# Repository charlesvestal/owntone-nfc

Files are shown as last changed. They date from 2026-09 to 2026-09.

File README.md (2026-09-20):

# owntone-nfc

An NFC "vinyl jukebox" for the Raspberry Pi. Put a card on the reader and an
album plays; take it off and it stops.

Audio goes to a local speaker, to AirPlay 2 speakers such as HomePods, or both.
When a card is removed and the grace period expires, the AirPlay session is
released so the speakers are free for anything else in the house — and your
speaker choice is remembered for the next card.

## The idea

Simulate a record player. Put the record on, it plays from the start. Take it
off, it stops. The card is a physical object that does exactly one thing, and
nothing about the interaction is hidden in an app.

That constraint drives the design: no resume position, no skip button on the
box, no state the card secretly carries. Anything player-shaped — transport,
volume, speaker selection, browsing — belongs to OwnTone's own web UI, which
already does it well. This project builds only what OwnTone cannot: turning a
card on a reader into playback.

## How it works

**OwnTone** owns the music library, playback, and the audio outputs. It is the
only mature AirPlay 2 *sender* on Linux, and since v29.0.139 it defaults to
AirPlay 2 with PTP timing, which is what keeps a HomePod stereo pair in sync.

A small Python service reads card presence from a **PN532 NFC HAT** over UART
and drives OwnTone through its JSON REST API.

| Module | Responsibility |
|---|---|
| `reader.py` | Card presence. Emits `card_present(uid)` / `card_removed()`, nothing else. |
| `owntone.py` | Thin REST client. Knows nothing about cards. |
| `cards.py` | UID → album mapping, persisted as YAML. |
| `outputs.py` | Speaker-selection snapshot, so the choice survives a release cycle and a reboot. |
| `controller.py` | The state machine. The only file with interesting logic, and where the tests live. |
| `web.py` | Card registration, and the admin page. Deliberately tiny. |
| `cardart/` | Finds cover art for albums still awaiting a card and lays it out as print-ready A4 sheets. Off the playback path entirely. |

Card mappings store **library-root-relative paths**, never absolute paths and
never OwnTone's numeric IDs — so a rebuild onto a new SD card doesn't cost you
a single re-registration.

Every album is meant to have exactly one card. Nothing in the format enforces
it, so the admin page flags any album holding more than one — with a hundred-odd
cards registered, a duplicate is otherwise invisible until two of them turn out
to play the same record.

## Hardware

| Part | Notes |
|---|---|
| **Raspberry Pi 4** | A 3B+ would likely do. Built and tested on a Pi 4. |
| **Waveshare PN532 NFC HAT** | Sits on the GPIO header. Any PN532 board with a UART mode works. |
| **NFC cards or tags** | See the note on card types below. |
| SD card | 16GB is plenty if the music lives on a NAS. |
| Speakers | Anything OwnTone can drive: the Pi's 3.5mm jack, a USB/I2S DAC, or AirPlay 2 speakers such as HomePods. |

### Configuring the HAT

**Set it to UART**, not I2C or SPI. This matters: `nfcpy` is the library with a
real card-*presence* API rather than read-a-UID-once, and it does not support
I2C at all. Continuous presence detection is the entire product - the card has
to keep saying "I am still here".

**DIP switches** — 1–6 OFF, 7 and 8 ON:

| # | 1 | 2 | 3 | 4 | 5 | 6 | 7 | 8 |
|---|---|---|---|---|---|---|---|---|
| Signal | SCK | MISO | MOSI | NSS | SCL | SDA | **RX** | **TX** |
| Set to | OFF | OFF | OFF | OFF | OFF | OFF | **ON** | **ON** |

**Jumpers** — the two labelled `I0`/`I1` (or `L0`/`L1`) set the chip's protocol,
separately from the DIP switches. For UART both go to **L**. Get the switches
right and the jumpers wrong and the reader sits there silent.

**Leave `RSTPDN` jumpered to `D20`.** The service pulses that line to reset the
PN532 when it stops responding, which a restart can cause. Without the jumper a
wedged reader needs a power cycle.

`provision.sh` handles the Pi side: freeing the serial console and putting the
real PL011 UART on GPIO14/15 (the mini-UART's baud rate drifts with the VPU
clock and gives a reader that works only intermittently).

### Card types

**For new cards, buy NTAG213 or NTAG215.** Different tags report presence very
differently: motionless on the same reader, an NTAG213 held continuously for 11
seconds, while a 4-byte card was reported absent and re-found about 29 times a
second. That flicker is how the PN532 answers a re-select for that technology,
not the card moving — and the debounce absorbs it completely, with 19x margin
measured. Both kinds work; NTAG simply starts with more room.

The UID tells you which you have — 7 bytes starting `04` is an NTAG, 4 bytes is
Mifare-Classic-style. Insist on the chip name in the listing; "13.56MHz NFC
sticker" with no chip named is usually the wrong one. 213, 215 and 216 differ
only in memory, which does not matter here: the card carries no data, only its
UID.

Presence is debounced in software to cope, tuned by `presence_debounce_s`. If
cards stutter or fail to play, measure yours with `spikes/presence_check.py`
and raise that value. Measure with your least reliable card, not the first one
to hand.

### If it goes in an enclosure

Test networking in its final position before assembling everything, and **put
it on 2.4 GHz**. This board's 5 GHz receive path does not work: it associates,
completes the handshake, reports itself connected — and receives nothing. Not
"less", nothing. Transmit negotiates 390 Mbit/s while receive sits pinned at
6 Mbit/s, the floor, and zero bytes arrive. DHCP timing out is the first
symptom you notice, not the fault.

This was blamed on signal margin for a long time, and that was wrong: it fails
at -63 dBm just as completely as at -69, while a Mac in the same room uses the
same 5 GHz AP at -73 dBm without trouble. Don't go hunting for a few dB.

The failure is binary rather than gradual, and it does not announce itself.
[`docs/runbook.md`](docs/runbook.md) has the measurements and the four
plausible explanations that turned out to be wrong.

## Getting started

Burn Raspberry Pi OS Lite 64-bit, then:

```bash
git clone <this repo> /home/pi/owntone-nfc
sudo bash /home/pi/owntone-nfc/deploy/provision.sh
```

Copy albums to `/srv/music/<Artist>/<Album>/` (Samba share at
`smb://jukebox.local`), then open **http://jukebox.local:8080**, tap a card,
pick an album, save.

The same page collects cover art for albums that have no card yet, so you can
print a sheet of them. A search that picks the wrong cover can be corrected by
pinning a specific image URL; those corrections are hand-made judgements and
`backup.sh` keeps them alongside the card registry.

Pick your speakers in OwnTone at **http://jukebox.local:3689**. The jukebox
remembers them.

### Registering a stack of cards

Kneeling next to the box to register a shelf of albums gets old. Plug a USB
NFC reader into your laptop instead:

```bash
python3 -m pip install pyscard
python3 tools/desk_reader.py --host jukebox.local:8080
```

Tap a card, pick the album in the Register tab, save, tap the next. Each tap
prints `known card` or `NEW card`, so you can work through a pile without
watching the browser.

The scan is **identification only** — it cannot start, stop or switch a
record, so registering at a desk never interrupts what is playing in the
room. `--dry-run` prints UIDs without telling the jukebox, and `--silence`
turns off the reader's beep for good.

Tested with an ACS ACR122U, which reports UIDs byte-identical to the PN532 on
the box. Worth confirming that for any other reader before registering a
stack: scan a card you have already registered and check it matches
`cards.yaml`. Some readers report the UID byte-reversed, which would leave
every card you register pointing at nothing.

## Documentation

- **[`docs/runbook.md`](docs/runbook.md)** — hardware settings, the Wi-Fi and
  AirPlay gotchas, a symptom table, and how to rebuild. **Read this first when
  something is broken.**
- **[`docs/superpowers/specs/`](docs/superpowers/specs/)** — the design, and
  what hardware testing proved wrong about it.

## One thing worth knowing

**`user_agent = "AirPlay/999.0.0"` is required in `owntone.conf`.** Apple OS 27
gates `GET /info` on the User-Agent and returns 403 to OwnTone's default, so
AirPlay speakers stop working as they update. `provision.sh` sets it. Upstream:
[owntone#2042](https://github.com/owntone/owntone-server/issues/2042).

Environment-specific troubleshooting — networking, enclosures, recovery — is in
[`docs/runbook.md`](docs/runbook.md).

## Development

```bash
python3 -m venv .venv && .venv/bin/pip install -e '.[dev]'
.venv/bin/pytest
```

The suite runs on macOS with no hardware: `nfcpy` is imported lazily and the
reader has a fake. Note what that means — the tests prove the state machine's
logic, not that OwnTone accepts the calls. Several bugs found on real hardware
were invisible to a green suite because the mocks encoded the same assumptions
as the code.

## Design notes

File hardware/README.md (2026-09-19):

# Stand

A slanted face that holds the card like a record on a shelf, with the Pi
mounted directly behind it and **the back left open**.

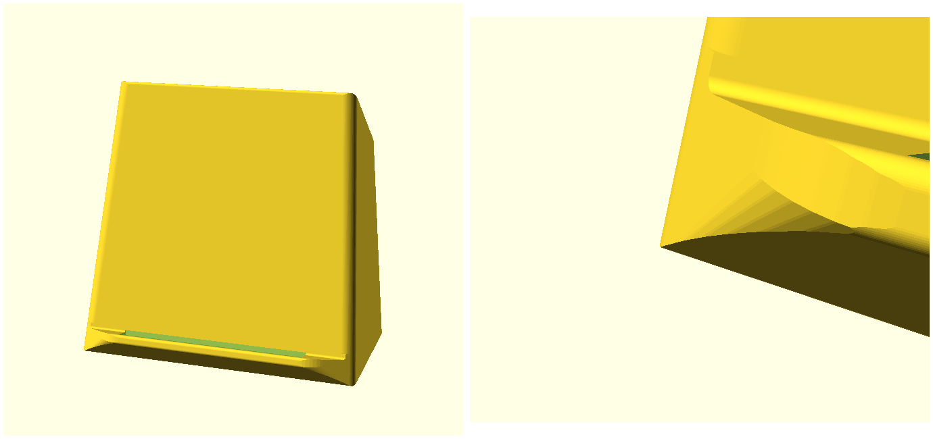
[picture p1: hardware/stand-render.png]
render


Rendered above: front, three-quarter, and the open back.

The open back is the whole idea. The Pi's ports face into it, so cables plug
straight into the board — no panel cutouts to get wrong, no internal extension
cables, and the airflow comes free. From the front you see a sleeve on a
stand; everything else is behind it.

The 15° lean means gravity holds the card against the face. The current box
has it vertical, so a strip of felt is doing all the work.

## You screw in the HAT, not the Pi

They share the 85 x 56 mm footprint and the same hole pattern, so either will
bolt to the face — but only one is right. The coil has to be the thing nearest
the card. Mount the **Pi** to the panel and the HAT ends up behind it on the
GPIO header, roughly 20 mm further from the card with the Pi's ground planes in
between; it will read badly or not at all.

So: **HAT bolted to the face, coil toward the card, Pi hanging off the back of
it** on the GPIO header.

## Measure the gap first

The HAT's tall top-side parts — the 1x17 breakout and the 2x3 jumper block —
stand **7.6 mm proud** of the board (measured from Waveshare's STEP model), and
in this orientation they face the panel. That forces ~11 mm standoffs, which
puts the coil about **14 mm** behind the card.

**That gap, not the panel thickness, is what decides whether a card reads.** At
11 mm standoffs the thinned window over the coil buys nothing at all — it only
matters if the HAT is nearly touching the panel.

So print the gauge and find out what your cards actually tolerate:

```sh
openscad -o gauge.stl -D 'part="coupon"' stand.scad
```

Six hollow pads, 6–16 mm. Sit the HAT face down on a pad, put your **worst**
card on top — a 4-byte Mifare-style one, 78 of the 132 are that type — and run
`spikes/presence_check.py`. Watch the **presence cycle count**, not simply
whether it reads: a marginal gap reads fine held still and falls apart when a
card is set down.

Then pick:

- **If 14 mm reads solidly**, keep `standoff_h = 11` and set `window_t = face_t`
  (the window is pointless at that distance).
- **If it doesn't**, the coil needs to come closer, which means a relief opening
  in the panel for those tall headers — hidden behind the card — and short
  standoffs. That gets the coil to about 7 mm. Ask and I'll add it.

## Then the stand

```sh
openscad -o stand.stl stand.scad
```

Defaults give a ~120 × 123 mm face, 66 mm deep, for a 95 mm card. Everything is
parametric — card size, lean, lip, panel thickness, Pi hole spacing, antenna
window — at the top of `stand.scad`.

**Measure the tag, not the HAT.** The HAT is already in the file: Waveshare's
own dimension drawing gives an 85 x 56 mm board — the same footprint as the Pi,
not a short 65 mm HAT — with a 37.4 x 37.8 mm coil panel centred 17.0 mm along
the long axis and 2.3 mm across from the board centre, on the far side from the
GPIO header.

So the only thing to measure is where the tag sits on your cards, and that is
done: **30 mm in from the left edge and 65 mm down from the top, measured on the
back.** Viewing from the front mirrors left to right but not top to bottom, so
in the model's frame that is `tag_dx = 17.5`, `tag_dy = -17.5` — the lower right
quadrant from the front, however it looks from behind.

With the HAT unflipped that lands the Pi almost exactly centred (0.5 mm off),
needing only a 76 mm panel against the 120 mm the card already demands. Flipped
it would want a 144 mm one, so `hat_flipped = false`.

The model then works out where the Pi has to go to put the coil on the tag, and
`hat_flipped` mirrors the offset by turning the HAT end-for-end — which is
usually what decides whether the coil can reach the tag at all. Three assertions
catch the ways this goes wrong: bosses in the side wall, bosses in the base, and
a coil window running off the edge of the card.

The panel is thinned **from behind**, so the outside stays flat and rigid
while the reader only has `window_t` of plastic to see through.

## Design notes

Every visible edge is chamfered and the vertical corners radiused, so the form
catches light along its arrises instead of showing a raw printed corner. The top
is **cut back** rather than coming to a point, and the sides **rake inward** as they rise — the taper an arcade cabinet uses, and for the same
reason: straight sides read as a box, angled ones as a made object. The rake is
bounded by the card, which is square and cannot be encroached on.

The card **stands on a lip** and leans back against the face — gravity holds it,
which is the whole reason for the slant. The felt sits in a **recess** in the
lip's top so it finishes flush instead of proud, and the lip's underside is
chamfered back to the face: a ledge projecting from a panel that already leans
back is a full overhang, and would otherwise need support exactly where the
finish shows most. There is deliberately **no hole in the front**; a scallop cut
in the panel reads as damage rather than detail.

The **side walls carry back** to `back_h` of the front height, so the Pi and the
cavity aren't on show from the side. Lower looks lighter; too low and it's a
blade on a plinth.

There was a shadow reveal round the base too, to lift the body optically. It is
gone: the lip covers it across the front, so it ran three-quarters of the way
round and stopped, which reads as a mistake rather than a detail. The lip
already gives the front its horizontal line.

`face_w` takes the **larger** of "wide enough for the card" and "wide enough for
the Pi wherever your tag offset puts it". That second case is not hypothetical —
a mounting boss that lands on the side wall merges into it, vanishes from the
render, and is only discovered when the Pi won't screw down.

## Printing notes

- **Orientation**: base down, as modelled. The face is 15° off vertical, which
  is well within overhang tolerance, and the lip is chamfered underneath so it
  needs no support.
- **No metal near the face.** Screws, heat-set inserts and magnets all kill NFC
  coupling. The standoffs take self-tapping M2.5 straight into plastic.
- **Keep the Pi's USB-C/HDMI corner clear** of anything dense — that's the Wi-Fi
  antenna, and it has little margin to spare.
- **Felt**: `felt_w` / `felt_t` cut a recess in the lip so the strip finishes
  flush instead of sitting proud.

## Rendering on Apple Silicon

The Homebrew and 2021.01 OpenSCAD builds are Intel-only. Either install
Rosetta (`softwareupdate --install-rosetta`) or fetch an arm64 development
snapshot from openscad.org.

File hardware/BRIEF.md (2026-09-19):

# Brief: card stand for the NFC record player

## What the object is

A printed 95 × 95 mm album-art card stands on it, leaning back, displayed like
a sleeve on a shelf. A PN532 NFC HAT behind the card reads a tag in the card; a
Raspberry Pi 4 hangs off the HAT on its GPIO header. Put the card on, the album
plays; take it off, it stops. It lives in a living room next to speakers. **The
card is the interface and the hero — the object should be quiet.**

Design language: Dieter Rams. Continuous lines, nothing applied, nothing fussy.

## Hard constraints — all measured, none negotiable

| | |
|---|---|
| Card | 95 × 95 mm, ~0.5 mm thick, leans against the face |
| Tag in the card | centre **+17.5 mm right, −17.5 mm down** from the card's centre, **viewed from the front** |
| PN532 HAT | 85 × 56 mm board |
| HAT coil panel | 37.4 × 37.8 mm, centred **+17.0 mm along the long axis, +2.3 mm across** from the board's centre, on the opposite side from the GPIO connector |
| HAT tall parts | 1×17 header and 2×3 jumper block stand **7.6 mm proud** of the board and face the panel |
| Coil to card | ~14 mm. **Confirmed to read reliably — do not trade complexity to reduce it.** |
| Raspberry Pi 4 | 85 × 56 mm, hangs behind the HAT on the GPIO header; ~30 mm of stack |
| Pi ports | **face upward.** Forced, not chosen — see below |

**The HAT is the board nearest the card**, with the Pi behind it. Mounting the
Pi to the face instead puts the HAT ~20 mm further away with the Pi's ground
planes in between; it will not read.

**The coil must land on the tag.** That admits exactly one HAT orientation
(long axis horizontal, GPIO edge down), which is what forces the Pi's port edge
to face **up**. Everything else follows from this.

**Cables: the owner will not buy any.** Straight USB-C and 3.5 mm leads only.
A straight plug stands ~20–25 mm above the port plus bend radius, so either the
body is ~120 mm tall or **the back is genuinely open** and cables leave
rearward. The back should be open.

**No fasteners.** The owner has no M2.5 hardware and does not want to buy any.
Current solution, which works: the board's bottom edge drops into two seats and
leans **backward** onto two ribs — gravity holds it, as it does the card.

**Enclosed from normal view.** Solid face, solid sides. Nothing on the front
face but the card — no screws, no caps, no features.

## Printing

- FDM, Bambu, printed **base-down in one piece, no supports**.
- Nothing may overhang more than ~45° from vertical.
- Watertight: one connected component, zero non-manifold edges, flat bottom at z=0.

## The unresolved problem

**Where the lip meets the face, at the corners.** Everything else is settled.

The owner's words, in order, over six failed attempts:

> "the lip's edges and the body's don't meet well. there's a curve into a hard edge, instead of anything continuous"
> "think continuous smooth lines", "dieter rams curves"
> "where the lip connects also needs to curve out to meet the face / edge of the body"
> "when viewed from above the contour of the body and the lip should look like this" — a sketch of a long straight front with an **S at each end** sweeping back into the body's sides
> "do you see how it reaches the OUTER flat edge as opposed to the FRONT flat face"
> "either make the lip the width of the uncurved part of the face or make that part of the face transition to the outer curve of the lip. the sharp transition has to go"

**Do not guess at this from the description — it has been guessed at six times
and got worse.** A plan view with a millimetre scale is at
`~/Desktop/jukebox-stand/plan-with-scale.png`; get the owner to mark the two
numbers, and build to them.

### What has already been tried, and why each failed

| Attempt | Why it failed |
|---|---|
| Lip as a separate solid, clipped to its own plan | Its corner arcs sat at a different depth from the body's; across the body's corner radius the lip stayed at full projection while the face was already turning away, so they met at an angle |
| Lip inset by `corner_r`, returning on a 15 mm arc | Crossed the face at ~66°, leaving a cusp; the return radius is not the problem |
| Larger return radii (26, 32 mm) | Shallower crossing but the shelf under the card's outer corners disappears |
| Cove (morphological closing) at the junction | Rounds concave plan corners, but the visible cusp is where the lip's chamfered *underside* converges — a 3D feature a 2D closing cannot touch |
| Explicit tangent S drawn as a polygon | Correct in 2D, but destroyed by `hull()` — see traps |
| Lip narrowed to the face's flat width | Latest state. Still reads as reaching the body's outer edge |

## Traps — every one of these cost a cycle

- **`hull()` takes the CONVEX hull.** It silently deletes concave plan geometry. An explicit S-curve was erased by it twice before this was spotted. Loft with successive hulls only where the outline is convex.
- **Exact coincidence or tangency between solids produces non-manifold edges** in CGAL. A lip meeting a panel at exactly zero volume became a separate shell; cone bases sitting exactly on a wall produced bad edges; a lip ending exactly on a tangent point produced four. Always overlap by a few tenths.
- **`offset(r = -n)` on a 2D profile shrinks it in BOTH axes.** Using it to compensate for a Minkowski sum ate 5 mm of the lip's height and deleted it.
- **Features built in the face's tilted frame do not respect the base plane.** The lip and the boss cones both hung below z=0. Trim the whole part to z ≥ 0.
- **A cutter that runs past its target keeps cutting.** With the coil window's thinning disabled, its cutter still carved 4 mm behind the panel and put gaps in the standoff cones.
- **The panel leans back, so gravity pulls the board AWAY from it.** An earlier design had the board resting on the panel; it would have fallen off. It must lean backward onto ribs.
- **Printed bosses off the face are infeasible.** The coil reaches within ~3.3 mm of the HAT's mounting holes, and a boss 11 mm off a near-vertical face needs ~15 mm of 45° gusset, which lands on the coil. A snap cantilevered off the panel is the same mistake.
- **Two modules with the same name:** OpenSCAD silently uses the last one. A stale `body()` was rendered for several rounds.

## Verification — not optional

OpenSCAD (native, universal binary; the Homebrew one is Intel-only and Rosetta
is not installed):

    /Users/charlesvestal/.claude/jobs/323f8796/tmp/oscadmnt/OpenSCAD.app/Contents/MacOS/OpenSCAD

**Render front, three-quarter, back, side and a TOP/PLAN view, and LOOK at
every one with the Read tool.** Several faults here were invisible in a
three-quarter view and obvious in plan. Do not declare anything done without
looking. Save renders where the owner can open them — they cannot see images
that are only read.

**Then run the owner's own slicer**, which is the authority:

    /Applications/BambuStudio.app/Contents/MacOS/BambuStudio --info file.stl

It reports `manifold` and `number_of_parts`. It caught a floating snap hook
that both a render and a hand-rolled mesh check had missed. Nothing goes to the
owner without `manifold = yes` and `number_of_parts = 1`.

## Where things are

- `hardware/stand.scad` — current design, v1 shape: tapered wedge, raked sides, open back, integral lip, seats and ribs, no fasteners. **This is the shape the owner wants.**
- `hardware/stand2.scad` — an alternative that was rejected (open at the top).
- `~/Desktop/jukebox-stand/` — STLs and renders the owner looks at.

## Deliver

A corrected `hardware/stand.scad`, renders in `~/Desktop/jukebox-stand/`, an
STL that passes both the mesh check and the slicer check, and a plain statement
of what was changed and anything still unresolved. Do not commit to git.

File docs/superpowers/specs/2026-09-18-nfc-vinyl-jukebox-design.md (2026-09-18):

# NFC Vinyl Jukebox — Design

**Date:** 2026-09-18
**Status:** Approved, pending Spike 0

## Goal

Rebuild a contactless RFID/NFC music player on a Raspberry Pi. Placing an NFC card
on the reader plays an album; removing it stops playback. Audio must be able to go
to a local speaker *or* to AirPlay 2 HomePods, and the HomePods must be released
when playback ends so they are free for other senders.

**North star: simulate vinyl.** Put the record on, it plays from the start. Take it
off, it stops. The physical object is honest — no skip button, no resume, no state
hidden in the card.

## Why not Phoniebox

The previous build used Phoniebox. It remains the dominant project and v3 (Python
rewrite) is near-default, but it is the wrong fit here for one reason: **MPD, its
playback engine, has no AirPlay output at all.**

The only documented Phoniebox+HomePod recipe requires Phoniebox v2 + MPD on a
non-default port + OwnTone + PulseAudio + `snd-aloop` + patched shell scripts. Its
author describes it as "very convoluted" and reports that **v3's PulseAudio layer
would not pair with HomePods**. Adopting it means carrying local patches against a
moving upstream, and local-vs-AirPlay switching stays awkward because MPD has no
concept of AirPlay.

OwnTone (formerly forked-daapd) is the only mature AirPlay 2 *sender* on Linux.
Since v29.0.139 its default AirPlay mode is AirPlay 2 with PTP timing. It treats
local ALSA and AirPlay devices as peer outputs on one synced timeline, and exposes
output selection over a documented REST API. Building on it directly removes the
entire hack stack.

Note: the repo directory is named `phoniebox-nfc` for historical reasons. Phoniebox
is not used.

## Hardware & OS

| Item | Choice | Rationale |
|---|---|---|
| Board | **Pi 4** (3B kept as spare) | Better Wi-Fi radio — AirPlay 2 PTP is sensitive to flaky Wi-Fi. Headroom, USB 3 for a future DAC. |
| OS | **Raspberry Pi OS Bookworm Lite, 64-bit** | Driver/library maturity for the PN532. Nothing here requires Trixie; cheap to revisit. |
| Reader | **PN532 HAT over UART** | `nfcpy` is the library with a real *card-presence* API rather than read-UID-once. It supports PN532 over serial and USB but **not I2C**. The vinyl model depends on reliable presence detection, so UART it is. |
| Audio | Onboard 3.5mm initially | AirPlay bypasses the Pi DAC entirely, so onboard only caps the local path. |

### UART consequence

Set the HAT's DIP switches to UART. Free the serial console and add
`dtoverlay=disable-bt` so the good PL011 UART lands on GPIO14/15 instead of the
mini-UART. Wi-Fi is unaffected; we give up onboard Bluetooth, which costs nothing
in this design.

### Audio upgrade path (deliberately deferred)

An I2S DAC HAT needs GPIO18/19/20/21 plus power, which does **not** collide with the
PN532 on UART — so it can stack. A USB DAC avoids the GPIO question entirely and is
the zero-risk option. Neither is needed to ship.

## Architecture

Four pieces, each independently testable:

- **OwnTone** (from its apt repo) — owns the library at `/srv/music`, exposes local
  ALSA + HomePods as selectable outputs, provides the REST API and the player web UI
  on `:3689`. We configure it; we do not modify it.
- **`reader.py`** — wraps `nfcpy`. Emits exactly two events: `card_present(uid)` and
  `card_removed()`. Knows nothing about music.
- **`owntone.py`** — thin REST client. Knows nothing about cards.
- **`controller.py`** — the state machine joining them. The only place vinyl behavior
  lives, and the only part with interesting logic. Unit tested with both `reader` and
  `owntone` mocked.
- **`web.py`** — small admin app on `:8080`.

Runs as a single systemd service, `nfc-jukebox`.

## The vinyl state machine

**Card placed** → resolve UID → clear queue, add album, restore output selection,
play **from track 1**.

**Card removed** → **pause immediately**, start grace timer (default 90s).

- Same card returns within a **bump window** → resume in place. Contactless readers
  drop a read occasionally; restarting the album because someone nudged the box would
  be maddening. **Window length to be set by measurement in Spike 2, not guessed.**
  Prior art suggests sub-second: Phoniebox's equivalent setting has a minimum of 0.2s,
  chosen specifically to ride out brief missed reads. A window of seconds would be too
  long — a deliberate lift-and-replace would wrongly resume instead of restarting.
- Same card returns after the bump window → restart from track 1, per vinyl.
- Different card at any point → switch immediately.
- **Grace expires** → stop, clear queue, deselect AirPlay outputs so the HomePods go
  idle and are free for other senders.

The grace timer is why this does not feel laggy: AirPlay 2's PTP handshake costs a
couple of seconds, so the session is held through short gaps and only truly released
when the user is actually done.

## Output handling

**OwnTone owns output selection. We do not store an output mode.**

Its web UI already ships per-output volume and speaker selection, so duplicating that
would mean building a worse version of an existing UI. Instead the controller:

1. On release: **snapshots the currently selected outputs to disk**, then deselects
   the AirPlay ones.
2. On next card: **restores that snapshot** via `PUT /api/outputs/set`.

The user picks speakers in OwnTone's UI like any other AirPlay app and it sticks.
"It lives in one mode" falls out for free; switching modes is a checkbox in a UI that
already exists. Playing to local and AirPlay simultaneously is just a two-element
list — a mode, not an architecture.

**Guard rail:** if outputs are already selected while the box is idle (the user chose
them by hand), respect that rather than clobbering it with the snapshot.

**The snapshot is persisted to disk, not held in memory**, so a reboot does not lose
the speaker choice. *"Output actually sticks" is an explicit acceptance criterion,
verified across both a release cycle and a reboot.*

## Card mapping

`/etc/nfc-jukebox/cards.yaml`, keyed by UID hex:

```yaml
04a2b3c4d5e680:
  name: "Kind of Blue"
  path: "Miles Davis/Kind of Blue"   # relative to the library root
```

Entries store a **library-root-relative path, not an OwnTone numeric ID**, and are
queued via OwnTone's `expression` query against the path.

This is load-bearing for portability. Numeric IDs are assigned at scan time, so they
differ on every rebuild — every mapping would break when redeployed to a new SD card.
A relative path survives a new card, a local→NAS switch, and a change of mount point.
Re-registering cards after a rebuild is the one thing this system must never require.

Consequence: the `library:album:<id>` approach used by the Instructables build is
**ruled out**, not merely riskier. Spike 1 verifies the expression syntax works, not
whether to use it.

## Music library

Local FLAC (and other local files). One folder per album under
`/srv/music/<Artist>/<Album>`, since the card mapping keys off that path prefix.

**Storage: music lives locally on the Pi — USB SSD or a large SD card. A NAS, if
used, is the master copy that we sync *from*, not a mount we play *through*.**

Two documented problems rule out mounting the NAS directly:

1. **No real-time updates.** OwnTone's docs: "if you have your library on a network
   mount then real time updating may not work" — most network filesharing protocols
   send no change notifications. Requires cron-driven `.init-rescan` trigger files.
2. **Boot-order fragility.** OwnTone issue #690: if the share is not mounted when
   OwnTone starts, the music stays unavailable *even after the share remounts*, and
   only a full rescan recovers it. A Pi that boots faster than the NAS wakes gives a
   silent box, and the failure is invisible until someone taps a card.

For an appliance that should behave like a record player, "works only if the NAS
happened to be awake first" is disqualifying. Local storage gives real-time inotify
updates, makes boot order irrelevant, and keeps the box working when the NAS or
network is down. A 256GB card holds a few hundred FLAC albums.

Populated by rsync from the NAS, or drag-and-drop onto the Pi's Samba share.

**Decided: the library root is a configurable mount point.** Both are supported:

- **Local storage** — simplest, real-time inotify updates, boot order irrelevant.
  Constrained by card size: the library is ~56GB and a 64GB card cannot hold it
  alongside the OS, so local means a *subset* until a larger card arrives.
- **NAS mount** — the answer to the capacity squeeze. The two problems above are
  mitigable, not fatal:
  - Boot ordering (#690): `x-systemd.automount` in fstab plus a
    `RequiresMountsFor=/srv/music` drop-in on `owntone.service`, so OwnTone cannot
    start before the mount exists.
  - No inotify: a cron job dropping an `.init-rescan` trigger file — OwnTone's own
    documented workaround.

Either can be chosen at deploy time without touching the card mappings.

Out of scope: Spotify, web radio, podcasts. (Apple Music is not possible — there is
no usable Linux client.)

### Audio quality ceiling — AirPlay vs local

AirPlay 2 to a HomePod is **ALAC 16-bit/44.1kHz**; OwnTone transcodes to it. Any
24/96 FLAC will never reach the HomePods at full resolution. This is an Apple
protocol ceiling, not an OwnTone limitation.

Consequence: **hi-res only ever pays off on the local output.** That is the real
argument for eventually adding an I2S or USB DAC. Over AirPlay, CD quality is the
ceiling regardless of spend — which is also why onboard audio is an acceptable
starting point.

## Web admin (`:8080`)

Scope is deliberately minimal — only what OwnTone cannot already do:

- **Learn mode** — live-displays the UID of whatever card is tapped; pick a folder,
  save. This is the card re-registration story: existing physical cards work
  unchanged because only their UID is ever read.
- **Mapping table** — view, edit, delete.
- **Status line** — current state and last error.

Everything player-related (transport, volume, queue, library browsing, speaker
selection) links out to OwnTone on `:3689`, which already provides all of it.

Explicitly out of scope: transport controls, resume-position, per-card output
settings, GPIO buttons, rotary encoder, status LED.

## Failure handling

**AirPlay takeover is expected behavior, not an error.** AirPlay receivers tear down
the current session when a new sender connects. Tapping a card while a podcast plays
in the kitchen will stop the podcast, exactly as hitting AirPlay from a phone would.
Nothing to build; it is the behavior inherent to the protocol.

The genuine failure mode is narrower: the device is unreachable, or mDNS has not
discovered it yet (notably in the first ~30s after boot). Then: **play locally
anyway and surface it on the status line. Never leave the box silent.**

Known Apple-side gotcha, documented by OwnTone: if a speaker deselects itself the
instant playback starts (log shows `ANNOUNCE request failed in session startup: 400
Bad Request`), the fix is **Apple Home → Allow Speakers & TV Access → "Anyone On the
Same Network"**. Apple's default of *"Only People Sharing This Home"* cannot be
satisfied by a Linux sender. This presents as a compatibility failure but is a
permissions one.

## Spikes — before building

### Spike 0: HomePod pair reachability (highest risk, do first)

Can OwnTone drive the HomePod stereo pair given it is associated with an Apple TV?

Standalone HomePods and stereo pairs are well-proven. HomePods **bound to an Apple TV
as home-theater speakers** are not covered in OwnTone's docs, and the Phoniebox
builder reported exactly this case as failing. In that configuration HomePods
generally stop advertising as independent AirPlay receivers.

Steps: install OwnTone, set Apple Home → Allow Speakers & TV Access → "Anyone On the
Same Network", check whether the pair appears and plays.

Fallbacks in order:
1. PIN-pair the Apple TV itself as the AirPlay target (*Settings → Remotes &
   Outputs*; required for Apple TV4 / tvOS 10.2+).
2. Un-bind the HomePods from the Apple TV so they are standalone targets — the
   known-good configuration.

**This gates the rest of the build. Everything else assumes AirPlay output works.**

### Spike 1: path-expression queueing

Verify `POST /api/queue/items/add?expression=...` reliably queues a whole album by
path prefix, in correct track order. ~10 minutes. Falls back to numeric IDs.

### Spike 2: PN532 presence polling over UART

Verify `nfcpy` gives stable continuous presence detection, and **measure the real
dropped-read rate to set the bump window**. Expect sub-second. Phoniebox has an open
issue, #1991, titled "Placing card starts the player, removal stops it doesn't work
anymore" — presence detection is the fragile part of the incumbent, which is a good
reason to own this state machine and to characterise it with real numbers.

## Testing

`controller.py` is the testable core, with `reader` and `owntone` mocked:

- card placed → queue cleared, album added, playback starts at track 1
- card removed → pause is immediate
- same card within bump window → resumes in place, no restart
- same card after bump window → restarts from track 1
- different card mid-playback → switches immediately
- grace expiry → stop, queue cleared, AirPlay outputs deselected
- output snapshot restored on next card
- outputs already selected while idle → snapshot does not clobber
- AirPlay output unreachable → falls back to local, playback continues, error surfaced

Integration, on-device and manual: output selection survives a full release cycle
**and a reboot**.

## Prior art

Surveyed before building. Nobody has built this exact combination (OwnTone + PN532
presence detection + vinyl semantics + local/AirPlay peer outputs).

| Project | Status | Why not this |
|---|---|---|
| [lennyomg "Record Player"](https://www.instructables.com/Record-Player-a-Real-Player-That-Plays-Fake-Record/) | Published Apr 2025 | **Strongest prior art — independently arrived at this same architecture.** |
| [cleverdevil/musicbox](https://github.com/cleverdevil/musicbox) | Archived, 1★, Jan 2023 | Closest in intent — "NFC-powered AirPlay music box". Two Python files, tap-to-play only, AirPlay-only, one hardcoded HomePod, maps tags by filename (`[tagid].mp3`). Uses **pyatv**, not OwnTone. |
| [TagTuner](https://github.com/luka6000/TagTuner) + Music Assistant | 99★, active | The real competing ecosystem, and its pitch matches the vinyl goal. Rejected on evidence — see below. |
| [Gudsfile/jukebox](https://github.com/Gudsfile/jukebox) | 4★, active | Closest philosophically ("vinyl or CD tagged with NFC tags") but targets Spotify/Sonos. |
| [zacharycohn/jukebox](https://github.com/zacharycohn/jukebox) | 20★, stale 2023 | Sonos. |
| [layereight/nfc-music-box](https://github.com/layereight/nfc-music-box) | 51★, active | A build guide, not software. |

### Why not Music Assistant

Music Assistant is mature, actively developed, and runs standalone (Home Assistant
optional), so it was a serious candidate. Rejected on a documented technical point:
its own docs state the **AirPlay 2 implementation "is new and has not yet been
extensively tested"**, and specifically that **PTP timing is not yet supported**.

OwnTone has defaulted to AirPlay 2 *with* PTP since v29.0.139. For a HomePod stereo
pair, PTP is what keeps the two speakers in sync. This is the deciding factor.

### Borrowed

- **pyatv** as a Spike 0 diagnostic: `atvremote scan` enumerates what the HomePod pair
  actually advertises, far faster than diagnosing through OwnTone's UI.
- **Phoniebox's 0.2s grace-period minimum** as calibration for the bump window.

### The "Record Player" build (closest match)

An Instructables build from April 2025 independently reached four-for-four on our
load-bearing decisions: **OwnTone** as the media server, **PN532** as the reader,
output to "local speakers or Apple HomePods", and a **Python app driving OwnTone via
its API**. Someone has shipped this architecture and lived with it.

Differences, and what we take from them:

- **It maps tags to numeric `library:album:123456789` IDs** — the thing Spike 1 was
  designed to avoid. Someone running this in production on numeric IDs is evidence
  they may be stable enough in practice, which makes Spike 1 cheaper: if path
  expressions give trouble, numeric IDs are a proven fallback rather than a guess.
- **Output switching is a physical rotary switch** (local vs remote speakers) — the
  same insight as our snapshot-and-restore, implemented in hardware. Confirms that
  "it lives in one mode" is how these actually get used.
- It also streams Spotify; we are local-files-only. No architectural impact.
- Its physical build (N20 motor spinning a printed disk, NeoPixels, Li-Po + PowerBoost,
  XIAO satellite board, 3D-printed body) is out of scope here.

## Verified against OwnTone's source (2026-09-18)

Two assumptions in the original design were wrong, and both would have produced a
device that silently did not work. Neither was catchable by the test suite, because
the mocks were written from the same assumptions as the code. Both were settled by
reading OwnTone's C source rather than waiting for hardware.

### Output `type` strings

From the `.name` field of each `struct output_definition` in `src/outputs/*.c`:

| Backend | `type` value |
|---|---|
| airplay.c | `AirPlay 2` |
| raop.c | `AirPlay 1` |
| alsa.c | `ALSA` |
| pulse.c | `Pulseaudio` |
| cast.c | `Chromecast` |
| streaming.c | `streaming` |

The code compared `type == "airplay"`, which matches **nothing**. Consequences:
`airplay_output_ids()` always returned empty, `local_output_ids()` returned every
output *including the HomePods*, and `_release()` re-selected them — so the HomePods
would never have been released. That is the headline requirement, failing silently.

Two corrections follow:
- AirPlay detection is a casefolded prefix match, covering AirPlay 1 and 2.
- "Local" is an **allow-list** (`ALSA`, `Pulseaudio`), never "anything not AirPlay".
  A deny-list would have selected a neighbour's Chromecast and OwnTone's HTTP
  `streaming` output on every release.

### Smart-playlist expression grammar

From `src/parsers/smartpl_lexer.l`: valid tokens include `path` (string tag),
`includes`, `starts with`, `order by`, `asc`/`desc`, and the integer tags **`disc`**
and **`track`**.

`disc_number` / `track_number` are **JSON-API track-object field names**, not
expression grammar. The original expression would have failed to parse, returning
400 on every card tap — nothing would ever have played. Confusing these two
vocabularies is the whole bug.

### The lesson for the remaining spikes

Source-reading closed two binary risks cheaply, but it is not a running server.
Still unverified and still requiring Spikes 0-2:

- whether OwnTone *parses* the corrected expression, and whether `path` is the full
  filesystem path that the anchoring fix assumes
- whether `PUT /api/outputs/set` actually raises for a powered-off speaker, or
  returns 204 and fails asynchronously — in which case the box goes silent and no
  current code path notices
- the real PN532 reacquisition time, which sets the bump window

## Spike results on hardware (2026-09-18)

All three spikes ran on the real Pi. Several findings contradict what this
document assumed; the assumptions are corrected below rather than edited out,
because what was wrong is the useful part.

### Spike 0 — AirPlay: PASSED

**The HomePods work, associated with the Apple TV, with no PIN pairing and no
un-binding.** The single required change was on Apple's side:

> Home app -> Home Settings -> **Allow Speakers & TV Access -> "Anyone On the
> Same Network"**

Before that change, selecting them succeeded and then they deselected
themselves seconds later, with `Pairing step 1 ... Missing or invalid public
key` / `requires a valid PIN or password` in OwnTone's log. Apple's default of
*"Only People Sharing This Home"* cannot be satisfied by a Linux sender.

Corrections to this document's assumptions:

- **A stereo pair does NOT appear as a single AirPlay target.** OwnTone lists
  `HomePod Left (2)` and `HomePod Right` as two independent outputs. Selecting
  both gives real stereo (confirmed by ear). The output snapshot stores a list,
  so this needed no design change - but "tick two boxes, not one" is the actual
  user experience.
- **`requires_auth` / `needs_auth_key` in `/api/outputs` were `false`** on both
  devices while OwnTone's log demanded a PIN. Those flags cannot be used to
  detect a pairing requirement.
- **AirPlay volume is bidirectional.** A volume set through OwnTone was
  overridden by the HomePods' own reported level (set 12, read back 27). The
  device has final say.

**macOS is NOT usable as a test receiver.** macOS 27 returns `403 Forbidden` to
an unauthenticated `/info` probe - *including from the Mac to itself over
loopback*, which rules out network, firewall and sender identity. It wants the
HomeKit handshake before it will answer at all. No setting fixes this, and the
staged "Mac first as a positive control" plan was therefore dead on arrival.

### Spike 1 — album expression: three real bugs

See the "Verified against OwnTone's source" section above for the type strings
and lexer tags. On a live server, additionally:

- **Ordering is not optional.** With no `order by`, a 16-track album came back
  as `6 5 12 7 3 8 1 14 ...`. "Card on plays from track 1" would have been
  broken on every album.
- **Multi-field ordering is a syntax error.** `order by disc asc, track asc`
  returns 500 - the comma is rejected. Exactly one sort field is allowed, which
  is why ordering is by `path` (keeps multi-disc albums in order from one card).

### Spike 2 — presence: 35ms

A stationary NTAG213 on the PN532 over UART showed a **35ms worst-case gap**
between presence reads over ~11s. The originally guessed 3s bump window was
~85x too long; a deliberate lift-and-replace would have resumed instead of
restarting. Set to 0.25s. Measured on a bare board - an enclosure will widen
the gap, and it is a config value precisely so retuning needs no code change.

### Latency

Card-tap-to-audio was ~2.3s and it was **not our code**: every OwnTone API call
costs 2-3ms, so all six round trips per tap total ~15ms. The delay was
OwnTone's `start_buffer_ms`, which defaults to 2250ms for compatibility with
AirPlay hardware from the 2000s.

| Output | before | after `start_buffer_ms = 500` |
|---|---|---|
| Local ALSA | 2300 ms | **550 ms** |
| HomePods | - | **2080 ms** |

HomePods stay at ~2s because that is the AirPlay 2 PTP handshake, not
buffering. **This is the measurement that justifies the 90s grace period**:
releasing the session on every lifted card would cost a 2s handshake to get it
back. That decision was originally made on intuition; it is now measured.

### Reliability finding: the PN532 wedges on restart

Killing the service mid-transaction - which a plain `systemctl restart` does -
leaves the PN532 out of frame sync. Every subsequent open then fails with
`ETIMEDOUT` **forever**; reopening the port never recovers it, and nothing
holds the port. Only pulsing the chip's active-low `RSTPDN` line clears it.

On this HAT that line is jumpered to GPIO20. The reader now pulses it after two
consecutive open failures and recovers unattended in ~4s, verified on hardware.

Note this is a cure, not a prevention: the root cause is that SIGTERM does not
close the nfcpy frontend. Handling SIGTERM to close it cleanly would stop the
wedge happening at all and make the reset a genuine backstop. Worth doing.

## AirPlay: what actually works (settled 2026-09-18)

**Use both HomePods directly, selected as two outputs. That is real stereo.**

Verified with a generated hard-panned test file (`ZZ Test/Stereo Test/` in the
library - 4s of 440Hz in the left channel, 4s of 880Hz in the right, then both):
each tone came from its own speaker. OwnTone opens two independent AirPlay
sessions and the HomeKit pair renders its assigned channel from each.

Keep that test file. It is the only unambiguous way to answer "is this stereo",
and impressions are not reliable - during this session both "it sounds like
stereo" and "left plays only the left channel" were asserted and neither
survived the actual test.

### The Apple TV route is a dead end with OwnTone

Do not re-attempt without new information. What was established:

- The Apple TV is the **group leader** for the HomePods (`igl=1`, shared
  `gid`), so it looked like the correct single target for a stereo pair.
- With the User-Agent fix it pairs, accepts the session, shows the track
  name, and **honours seek commands** - so RTSP control works.
- But the **playhead never advances on the device, no album art appears, and
  no audio is produced**, while OwnTone's own clock runs normally and logs no
  error. The audio stream is accepted and never consumed.
- PTP timing is not the cause: OwnTone holds ports 319/320 throughout, and the
  same OwnTone drives the HomePods perfectly.

Best explanation: as a group leader the Apple TV expects AirPlay 2 *group*
semantics that OwnTone does not implement. That is upstream, not configurable.

### Apple OS 27 breaks AirPlay senders - one config line fixes it

OS 27 (HomePod / tvOS / macOS, AirTunes `srcvers` 980.x) gates `GET /info` on
the **User-Agent header** and rejects OwnTone's default with 403, *before* any
authentication. Fix, in `/etc/owntone.conf`:

```
user_agent = "AirPlay/999.0.0"
```

Proven on one device, same URL, header the only variable: default -> 403,
`AirPlay/999.0.0` -> 200. Upstream: owntone/owntone-server issue #2042.

**This is the most consequential finding of the build.** Without it the project
dies device by device as each one updates. The diagnosis was nearly missed: three
devices failed with a clean version correlation and the conclusion drawn was
that Apple had closed AirPlay to third-party senders. It had not.

Worth recording the trap, because it is a good one: earlier, changing Apple
Home's *Allow Speakers & TV Access* to "Anyone On the Same Network" **did** fix
the HomePods - they were on OS 26.6, where that genuinely was the cause. The
same change did nothing for the OS 27 devices, whose failure looked identical.
A real fix for one class of device masked a completely different cause in
another. The upstream reporter hit the same false positive four times over two
weeks.

## Resume reverses "always from the beginning" (2026-09-18)

The state machine above says a card returning after the bump window restarts
from track 1, and that the grace expiry stops playback and clears the queue.
Both are now wrong, and the owner reversed the decision himself:

> "shouldn't a pick up and put down resume if done within X time? honestly it
> should be within like an hour or something. what if you just want to pause?
> that's the vinyl way. in fact, should we just keep the state until another
> album is played?"

He is right, and the original rule was made before the box existed. **Lifting a
card is how you pause a record player**, and the north star above - "no resume"
- confused the physical honesty of the object (no hidden state on the card, no
skip button) with punishing the user for taking the record off. A real turntable
does not restart the side when you lift the tonearm.

**The model is now: the record stays on the platter until a different one is
put on.**

- Same card back → resumes, however long it has been.
- Different card → clears the queue and starts that album from track 1.
- Album reaches its natural end → the place is forgotten; the next tap is fresh.
- `resume_reset_hour` (default 3am, `null` to disable) draws a line under the
  day, so an album abandoned at midnight is side one again in the morning.
- A **Start over** button on the admin page is the only way to rewind mid-side.
  This is the one transport control the page carries, and it exists precisely
  because pause-on-lift took the old one (lift and replace) away.

Consequences worth recording:

- **The grace expiry no longer stops or clears.** It deselects the AirPlay
  outputs and nothing else. Releasing the speakers was always the requirement -
  the HomePods must go idle for other senders - and the stop-and-clear was
  incidental to it. Keeping the queue is what preserves the position.
- **A resume has to re-select the outputs**, since the release handed them
  back. Resume is therefore output-selection plus `play`, not `play` alone.
- **`bump_window_s` is gone.** Measured at 35ms and set to 0.25s in Spike 2, it
  existed only to tell a dropped read from a deliberate lift. Both resume now,
  so it had nothing left to decide. Unknown config keys are ignored, so boxes in
  the field are unaffected.
- **The position is not persisted, deliberately.** It lives in OwnTone's queue,
  which a restart of OwnTone or of the Pi empties; a persisted memory of a
  position that no longer exists would only produce a confident resume into
  silence. The controller therefore asks OwnTone whether the queue is still
  there before resuming, and falls back to starting the album.
- **Two clocks.** Everything durational stays on the monotonic clock. The
  nightly reset is the one wall-clock question in the system, and takes a
  separate injected time source rather than replacing the existing one.

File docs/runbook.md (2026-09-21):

# Jukebox Runbook

Operational notes for the NFC vinyl jukebox. Design rationale lives in
`docs/superpowers/specs/2026-09-18-nfc-vinyl-jukebox-design.md`; this file is
what you want when something is broken or you are rebuilding.

## At a glance

| | |
|---|---|
| Host | `jukebox.local` (Wi-Fi 2.4 GHz `<2.4GHz-SSID>`, DHCP) |
| Admin page | http://jukebox.local:8080 — card registration only |
| OwnTone | http://jukebox.local:3689 — player, volume, speakers, library |
| Music | `/srv/music/<Artist>/<Album>/` — Samba share `smb://jukebox.local` (guest) |
| Card registry | `/etc/nfc-jukebox/cards.yaml` |
| Speaker snapshot | `/var/lib/nfc-jukebox/outputs.json` |
| Services | `nfc-jukebox`, `owntone` |
| Logs | `journalctl -u nfc-jukebox -f` / `journalctl -u owntone -f` |

## Hardware

**Raspberry Pi 4**, Raspberry Pi OS Lite 64-bit.

Bookworm was originally chosen because Phoniebox required it. **Phoniebox is
not used**, so that constraint does not apply and a newer release is fine -
`provision.sh` reads the codename from `/etc/os-release` and picks the matching
OwnTone repository, which publishes both bookworm and trixie.

**Waveshare PN532 NFC HAT**, on the GPIO header, **UART mode**:

- DIP switches 1-6 (SCK, MISO, MOSI, NSS, SCL, SDA) **OFF**; 7 and 8 (RX, TX) **ON**
- Jumpers **I0 = L and I1 = L** (the board's own table: UART is L/L)
- **RSTPDN jumpered to D20** — not optional, see "reader stops responding"

UART rather than I2C because `nfcpy` has no I2C support, and continuous
presence detection is the entire product. `dtoverlay=disable-bt` puts the real
PL011 on GPIO14/15; the mini-UART's baud rate drifts with the VPU clock and
gives a reader that works only intermittently. Onboard Bluetooth is sacrificed
and not missed.

## Wi-Fi: power save must stay OFF

**This is the single most expensive thing to rediscover.**

With `802-11-wireless.powersave` on (the default), this Pi associates normally,
completes the handshake, transmits at 260 Mbit/s — and receives at **6 Mbit/s**,
the floor. DHCP times out, nothing routes, and the box vanishes from the
network while believing it is connected. It looks exactly like a dead router, a
failing repeater, or a shielded antenna, and it is none of those.

```bash
nmcli connection modify <wifi-connection> 802-11-wireless.powersave 2
```

With it off: rx 433 Mbit/s, DHCP instant. Transmit suffers too: 263 Mbit/s
down to 24 with power save on. `provision.sh` applies this to every Wi-Fi
connection it finds, and on Trixie the setting survives a reboot despite
netplan generating the NetworkManager config. The setting lives only in
NetworkManager on the SD card, so a rebuild without provision.sh will hit this
again.

Diagnosing this took hours, mostly because the fix was applied early and then
buried under two other changes (a BSSID pin and a static IP) whose failure
masked it. **Change one thing at a time.**

## AirPlay

**`user_agent = "AirPlay/999.0.0"` in `/etc/owntone.conf` is required.** Apple
OS 27 (HomePod / tvOS / macOS, AirTunes `srcvers` 980.x) gates `GET /info` on
the User-Agent and rejects OwnTone's default with 403, before any
authentication. Without it, every Apple device stops working as it updates to
27. Upstream: owntone/owntone-server#2042.

**Apple Home → Home Settings → Allow Speakers & TV Access → "Anyone On the Same
Network".** Apple's default cannot be satisfied by a Linux sender; the symptom
is a speaker that deselects itself the moment playback starts.

**What works:** both HomePods selected as two separate outputs. That is real
stereo — verified with the hard-panned test file at `ZZ Test/Stereo Test/` in
the library. Keep that file; impressions about stereo were wrong twice.

**What does not work:** targeting the Apple TV ("Living Room"). It pairs,
accepts the session, shows the track and honours seeks, but never advances its
playhead or produces audio. Best explanation is that as AirPlay group leader it
expects group semantics OwnTone does not implement. Do not re-attempt without
new information.

**macOS is not usable as a test receiver** — macOS 27 returns 403 to an
unauthenticated `/info` probe even over loopback.

## Wi-Fi: use the 2.4 GHz SSID, not 5 GHz

**This board's 5 GHz path fails in the jukebox's normal position, and 2.4 GHz
works. Configure `<2.4GHz-SSID>`.** Everything below is the evidence, because
two earlier outages were blamed on the wrong thing.

Measured 2026-09-19, same board, same spot, minutes apart:

| Band | SSID | Channel | Signal | DHCP | Rate |
|---|---|---|---|---|---|
| 5 GHz | `<5GHz-SSID>` | 36 (non-DFS) | -69 dBm | **never completes** | - |
| 2.4 GHz | `<2.4GHz-SSID>` | 11 | **-58 dBm** | instant | 130 Mbit/s |

Eleven dB, and the difference between working and not. 2.4 GHz penetrates; the
box sits where it sits.

The 5 GHz failure is always the same and is thoroughly misleading: it
associates, completes the 4-way handshake, logs *"Connected to wireless
network"* - and then DHCP opens a transaction and gets nothing. The box is
alive and believes it is fine, while being completely unreachable.

### What this is NOT - four theories that were wrong

Each cost real time. Do not re-run them.

**Not DFS.** The earlier outage was blamed on the router defaulting 5 GHz to
channels 100/104/108/112, which are radar-protected, where a client may not
probe actively. Plausible, and wrong: on 2026-09-19 the identical failure
reproduced on **channel 36, a non-DFS channel**, with the router's 5 GHz band
correctly pinned. DFS is not necessary to produce this.

The signal-level explanation that replaced it is also wrong - see *Not the
signal level* below. The earlier "changing to channel 36 fixed it" result was
almost certainly neither the channel nor the margin; whatever it was, it did
not hold.

**Not a 2.4 GHz radio fault.** This runbook previously stated the board sees
zero 2.4 GHz networks, ever, and fails even a directed probe. That is no longer
true - after the 2026-09-15 rebuild onto Trixie (kernel 6.18.50) a scan shows
five 2.4 GHz networks, `<2.4GHz-SSID>` among them at the strongest signal of
any AP the board can see. If the fault was ever real, the newer firmware fixed
it. Note also that the two bands are *separate SSIDs* here, so the old
"forcing the 2.4 GHz band didn't work" test proved nothing: it was forcing a
profile for `<5GHz-SSID>`, which does not exist on 2.4.

**Not the signal level.** This runbook previously identified a cliff around
-67 dBm - -66 dBm worked, -69 dBm failed, twice. That is wrong. On 2026-09-20
the board associated with `<5GHz-SSID>` on channel 36 at **-63 to -65 dBm**,
*better* than the -66 dBm that reportedly worked, held the association for two
unbroken minutes, and passed **zero bytes**. A static address was configured so
DHCP was bypassed entirely, and it still could not reach the gateway.

So the failure is neither about margin nor about DHCP. `iw` during the attempt:

    rate=6.0/390.0    d_rx=0

Transmit negotiated 390 Mbit/s. Receive was pinned at 6.0 Mbit/s - the floor -
and not one byte arrived. **The 5 GHz receive path is dead on this board**, and
DHCP timing out is just the first thing you notice. For scale, a Mac in the same
room uses that same channel 36 AP at -73 dBm, ten dB weaker, with 0% loss.

**Not the enclosure.** The box ran for months in that same enclosure in that
same spot, and 2.4 GHz works fine inside it today. The enclosure does not
change, so it cannot explain a box that stops working.

### A USB Wi-Fi adapter is not currently needed

Earlier advice here was to buy one. With 2.4 GHz working at -58 dBm that is
unnecessary - and note that the jitter which once looked like a reason to buy
one turned out to be the 4 MB SMB read size, fixed in software (see *Read size*
above). Measure `rsize` before spending money on a radio.

A dongle remains the **only** route to 5 GHz on this box, since the onboard
5 GHz receive path is dead rather than marginal. That is a want, not a need,
while 2.4 GHz carries a FLAC in and two AirPlay streams out with a median
latency of 5 ms. If the box is ever moved somewhere 2.4 also fails, pick one whose
driver is in the mainline kernel so nothing has to be rebuilt when the kernel
updates: the **Alfa AWUS036ACM** (MediaTek MT7612U, `mt76x2u`, dual-band,
detachable antenna) or the cheaper **Panda PAU0B** (RT5572, `rt2800usb`).
Avoid RTL8811AU/8821AU/8812AU sticks (TP-Link Archer T2U/T3U and most cheap AC
dongles) - out-of-tree DKMS drivers are exactly the wrong property for an
appliance that must come back silently after a reboot.

## Wi-Fi: the current configuration

As left on 2026-09-19:

| Profile | Band | Autoconnect | Priority | Powersave |
|---|---|---|---|---|
| `<2.4GHz-SSID>` | 2.4 GHz | yes | 10 | off |
| `<5GHz-SSID>` | 5 GHz | **no** | 0 | off |

The 5 GHz profile is deliberately `autoconnect no`. Left enabled it grabs
`wlan0` at boot, spends 45 seconds failing DHCP, and can wedge the box off the
network entirely. It is kept only so it is there if the box is ever moved
somewhere 5 GHz is strong.

Verified by reboot: `wlan0` came back unattended in about 30 seconds on
`192.168.2.188`, -59 dBm, 130 Mbit/s, with `nfc-jukebox`, `owntone` and
`avahi-daemon` all active.

## The outage of 2026-09-19

**Cause: the box had no Wi-Fi configuration at all.** `nmcli con show` listed
only the wired connection, and `/etc/NetworkManager/system-connections/` was
empty. The card was rebuilt on 2026-09-15 and re-provisioned on 2026-09-18;
Raspberry Pi Imager's Wi-Fi setup did not take, and nothing noticed.

`provision.sh` made it silent. Its power-save loop only *modifies* Wi-Fi
connections that already exist, so with no profile it matched nothing, `|| true`
swallowed it, and provisioning reported success on a box that could not reach
the network. It now fails loudly in that case instead.

Worth knowing for next time: the symptom was `jukebox.local` not resolving,
which looks like mDNS. It was not. The way to tell in one step is to ping-sweep
the subnet and grep the ARP table for this Pi 4's OUI, `e4:5f:01` - absent
means it never got a DHCP lease, so the problem is the radio, not the name.

The router lists several stale `jukebox*` entries, all offline: `.188`
(`<pi-wlan0-mac>`, wlan0) and `.189` (`<pi-eth0-mac>`, eth0) are this Pi
4; `.224` and `.225` are `B8:27:EB:...`, earlier boards. The `-1/-2/-3` suffixes
are the Speedport disambiguating different MACs that all announced the hostname
`jukebox`. Not a name conflict on the Pi, and not a fault.

## Common failures

| Symptom | Cause | Fix |
|---|---|---|
| Box invisible on the network after a reboot | Wi-Fi power save | See above. Check `iw wlan0 link` — rx bitrate at 6 Mbit/s is the tell. |
| Box invisible and `jukebox.local` does not resolve | Usually no Wi-Fi profile, or `wlan0` on 5 GHz | First: `nmcli con show` — if there is no Wi-Fi connection, that is the whole answer. Confirm the box is absent rather than merely unnamed by ping-sweeping the subnet and grepping the ARP table for `e4:5f:01`; no entry means it never got a DHCP lease, so it is not mDNS. Then check it is on `<2.4GHz-SSID>`, not `<5GHz-SSID>`. |
| Reader stops responding; log shows `ETIMEDOUT` repeatedly | PN532 wedged out of frame sync, usually by a service restart killing it mid-transaction | Automatic: the reader pulses RSTPDN on GPIO20 after 2 failures and recovers in ~4s. If it does not, check the RSTPDN↔D20 jumper. Manual: `pinctrl set 20 op dl; sleep 1; pinctrl set 20 op dh` |
| A card plays nothing; status flaps play/pause | Card technology with unstable presence — 4-byte Mifare-style cards report present for ~8ms at a time | Already handled by `presence_debounce_s` (0.5s). If a new card still flaps, raise it. |
| An album plays shuffled or not from track 1 | Shuffle enabled in OwnTone's UI | The controller forces shuffle/repeat off per card. If it persists, check the log for an error on that call. |
| Speaker drops mid-album, status shows an error | AirPlay receiver refused pairing; OwnTone fell back to local | Check Apple Home access setting. The error names which output was lost. |
| Admin page shows no cards | Page-level failure, not data loss | Check `curl localhost:8080/api/cards` first — the registry is almost certainly intact. |

## Music on the NAS

The library is an SMB mount from the UGREEN NAS, mounted read-only at
`/srv/music` so the jukebox can never damage it.

```
//192.168.2.46/Media/music/library /srv/music cifs \
  credentials=/etc/samba/creds/nas,uid=pi,gid=pi,file_mode=0444,dir_mode=0555,\
  iocharset=utf8,ro,nofail,_netdev,x-systemd.automount,x-systemd.idle-timeout=600,\
  rsize=131072,wsize=131072 0 0
```

`provision.sh` writes this line for you if you pass the share, and re-running
it **updates** an existing entry rather than duplicating it - which is how the
read-size fix reaches a box built before it existed:

```
sudo NAS_SHARE=//192.168.2.46/Media/music/library bash deploy/provision.sh
```

Leave `NAS_SHARE` unset and `/etc/fstab` is left entirely alone. The address is
never committed: it is passed in, because this repo does not carry the home
network. Credentials are separate and are not written by provisioning.

**By IP, deliberately, not `//vestnas.local/`.** The hostname version worked
for weeks and then stopped: the NAS began advertising only an IPv6 address
over mDNS, and the Pi resolves with `mdns4_minimal`, which is IPv4-only. The
mount failed at boot with `could not resolve address for vestnas.local`, and
because both services required the mount, the box went completely silent -
no music and no admin page to say why.

Pinning the name in `/etc/hosts` is **not** a fix. `/etc/hosts` here is
managed by cloud-init and rewritten on every boot, so that repair survives
until the next restart and then fails exactly as before.

The cost of an IP is that it must not move: give the NAS a static address, or
a DHCP reservation on the router.

Credentials live in `/etc/samba/creds/nas` (`0600`, root). Recreate with
`sudo /usr/local/sbin/nas-creds charlesvestal`, which prompts rather than
taking the password as an argument.

### Read size: cap it at 128 KB, or playback stutters

**`rsize=131072` is not optional over Wi-Fi.** SMB3 defaults to 4 MB reads. On
this link that is about a second of airtime delivered as a single slug, and
everything else queues behind it - including AirPlay 2's PTP timing packets,
which are what keep a HomePod stereo pair in sync. The audible symptom is a
flanging or delay effect swelling in and out: the two speakers drift apart and
you are hearing comb filtering. It sounds like a speaker fault or an OwnTone
fault. It is neither.

Measured 2026-09-20, pinging the gateway while reading from the NAS with
`iflag=direct` so each read is exactly one wire request:

| Read size | Worst RTT | Pings over 200 ms | Throughput |
|---|---|---|---|
| idle | 74 ms | 0 of 80 | - |
| **4 MB** (the default) | **4517 ms** | **70 of 80** | 1.6 MB/s |
| **128 KB** | 189 ms | 0 of 80 | **2.0 MB/s** |

Smaller reads are *faster as well as smoother* - nothing is traded away. Across
one-minute samples, 4 MB reads put a spike above 200 ms into 41% of minutes;
with the cap, four consecutive minutes of playback peaked at 53.6 ms.

This also disposes of a whole class of symptom that reads as a Wi-Fi fault:
multi-second stalls, ping swinging from 7 ms to 400 ms, and the rx rate
collapsing from 72.2 to 39.0 Mbit/s while tx holds steady. That is self-inflicted
congestion from one large read, not a weak or broken radio. **Check the read
size before blaming the link** - an afternoon went into the radio before anyone
looked at `rsize`.

Three details that matter:

- **`x-systemd.automount` + `RequiresMountsFor=/srv/music`** on `owntone.service`
  only. If OwnTone starts before the mount exists, the music stays unavailable
  *even after it mounts later* - only a full rescan recovers (upstream issue
  #690). `nfc-jukebox.service` deliberately does **not** require the mount: it
  starts regardless, and `/api/status` reports `library_ok: false` with the
  reason, so a missing NAS produces a page that explains itself instead of a
  box that looks dead.
- **`nofail`** so a NAS that is off or asleep cannot stop the Pi booting.
- **Rescanning.** Network mounts send no inotify events, so OwnTone never
  notices new albums on its own, and the mount is read-only so OwnTone's
  `.init-rescan` trigger file is not an option either. `PUT /api/update` is the
  only route.

  **The nightly cron at 04:30 never ran, because the box is on a smart switch
  that cuts power overnight.** `/etc/cron.d/owntone-rescan` was correct and
  cron was healthy. Found 2026-09-20: OwnTone's `updated_at` was stuck three
  days back, and two manual scans took it from 168 to 172 albums and 2085 to
  2153 songs - four albums and 68 songs it had never seen.

  Measured across 2026-09-20/21: **power off at 22:07, back on at 05:36.** A
  04:30 `cron.d` job falls squarely inside that window and never fires, and
  without `anacron` cron never catches it up.

  The switch is easy to forget - it was briefly asserted here that this box
  runs continuously and is never switched off, which is wrong and sent a
  morning's debugging after a box that was simply unplugged. Hence the times,
  written down.

  **Reading logs across that power cut: there is no RTC on a Pi.** On boot,
  systemd restores the clock from `/var/lib/systemd/timesync/clock` - the last
  time written before power was lost - and only jumps to the real time once NTP
  syncs a few seconds later. So the first entries of every boot are stamped
  with *last night's* time:

      systemd[1]: System time advanced to timestamp on
                  /var/lib/systemd/timesync/clock: Sun 2026-09-20 22:07:03 CEST

  which makes `journalctl --list-boots` show a boot that appears to begin
  before the previous one ended, and looks for all the world like the box never
  rebooted. `uptime -s` is the honest answer. That saved timestamp is also the
  most precise record of when power was cut, since timesyncd writes it
  periodically: 22:07:03 on 2026-09-20, matching the last `wifi-watch` line at
  22:07:22 and OwnTone's last line at 22:07:24, all stopping mid-stream with no
  shutdown sequence.

  Use the **Rescan library** button on the admin page's System tab. It reports
  progress and the new counts. By hand:
  `curl -X PUT http://jukebox.local:3689/api/update`.

  **Done:** replaced by a systemd timer (`owntone-rescan.timer`) with
  `Persistent=true`, which runs the missed job shortly after the switch powers
  the box back up rather than skipping it. It also covers any other reason a
  run is missed, and `systemctl list-timers` shows when it last fired - cron
  offered neither, which is how a three-day-stale library went unnoticed.

The initial bulk scan of ~2,000 files took **520 seconds** over SMB on Wi-Fi.
That is a one-time cost; incremental scans are much faster.

**Card mappings were unaffected by the move from SD to NAS** - all seven
resolved with correct track counts immediately, because they store
library-relative paths. The NAS uses the same `<Artist>/<Album>/` layout.

The previous local copy is at `/srv/music.local`. Delete it to reclaim SD
space once you are happy with the NAS.

## Rebuilding onto a new SD card

1. `sudo bash deploy/backup.sh` on the old card; copy the archive off.
2. Burn Raspberry Pi OS Lite 64-bit. In Imager's settings: hostname
   `jukebox`, SSH with your public key, user `pi`, Wi-Fi, locale.
   **Give it the 2.4 GHz SSID**, and verify after first boot that
   `nmcli con show` actually lists it — the imager's Wi-Fi silently did not
   take on the 2026-09-15 rebuild, which is what caused that outage.
   `provision.sh` now refuses to run if no Wi-Fi profile exists.
3. `git clone` this repo to `/home/pi/owntone-nfc`.
4. `sudo bash deploy/provision.sh`
5. `sudo tar xzf jukebox-state-*.tar.gz -C /`
6. Copy music to `/srv/music`, preserving `<Artist>/<Album>/`.
7. `sudo systemctl restart owntone nfc-jukebox`

**Cards do not need re-registering** — mappings store library-relative paths,
so they survive a rebuild. The only thing that breaks them is changing the
`<Artist>/<Album>` folder layout.

## How the record behaves (changed 2026-09-18)

Lifting a card **pauses**; putting the same card back **resumes where it left
off**, however long it has been. The record stays on the platter until a
different one is put on.

- **Same card back** → resumes. No time limit.
- **Different card** → clears the queue and starts that album from track 1.
- **Album plays to its end** → the place is forgotten, so the next tap of that
  card starts side one.
- **Start over** on the admin page → restarts the loaded album from track 1.
  This is the only way to rewind a record mid-side.
- **Overnight** → `resume_reset_hour` (default 3am) draws a line under the day:
  an album loaded before the most recent 3am is no longer resumable, so a
  record abandoned at midnight starts fresh in the morning. Set it to `null` to
  turn that off.

**A reboot loses your place.** The position lives in OwnTone's queue and is not
persisted anywhere - restarting `owntone` or `nfc-jukebox`, or rebooting the
Pi, means the next tap starts from track 1. Nothing is broken when that
happens; it is the same as lifting the tonearm and switching the amp off. The
speaker choice is a different thing and *does* survive a reboot
(`/var/lib/nfc-jukebox/outputs.json`).

Note the grace timer no longer stops playback. At expiry it deselects the
AirPlay outputs - so the HomePods still go idle and are free for other senders,
which was always the point - and leaves the queue paused where it was.

## Retuning after the enclosure is built

The timing value is config, not code — edit `/etc/nfc-jukebox/config.yaml`
and restart:

- `presence_debounce_s` (0.5) — an enclosure adds air gap between card and
  reader, which will widen the absent-run. If cards start stuttering, raise it.

`bump_window_s` was removed on 2026-09-18 with the switch to resume-on-return:
a dropped read and a deliberate lift both resume now, so there was nothing left
for the window to decide. An old config file that still sets it is harmless -
unknown keys are ignored - but the line does nothing and can be deleted.

Re-measure with `spikes/presence_check.py` against the built box rather than
guessing. Note the original measurement was taken on one card type and did not
generalise: an NTAG213 held continuously for 11s, a 4-byte card dropped out
every 8ms. **Measure with the worst card you own, not the first one to hand.**

## Card technology: buy NTAG21x, not Mifare Classic

The UID tells you which you have: **7 bytes starting `04`** is an NTAG (good);
**4 bytes** is Mifare-Classic-style (flickers). As of 2026-09-20 the registry
holds 78 of the bad kind and 54 of the good.

**The 4-byte cards already registered are fine. Do not "fix" them.** Measured
2026-09-20 on `acd997ee` (José González/Veneer) sitting motionless on the built
box:

| | |
|---|---|
| present/removed episodes | 4325 in 150s (~29/s) |
| every hold | 0.01s |
| absence run, median | 26.1 ms |
| absence run, p99.9 | 26.5 ms |
| absence run, **worst** | **26.5 ms** |
| runs long enough to read as a lift | **0 of 1742** |

So the flicker is real and fast, and completely irrelevant: the absence run is
metronomic, p99.9 and worst differ by 0.1 ms, and `presence_debounce_s` at 0.5
has ~19x margin over it. Raising the debounce buys nothing and costs lag on
every lift. **This was proposed and rejected on the measurement.**

It also clears flicker of the 2026-09-19 play/pause glitch on this very card:
that was ~1.4s of absence, **53x the worst run this card produces**. Still
unexplained; look for something mechanical, not for a timing value to tune.

Re-measure with `spikes/presence_check.py` rather than reasoning about it. Both
probes used here pulse RSTPDN on GPIO20 first, because stopping the service
leaves the PN532 out of frame sync and the plain spike cannot open it.

For *new* cards buy **NTAG213 or NTAG215**, 25-30mm round wet inlay - better
engineered and with margin to spare, not because the existing ones misbehave. The chip name must be in
the listing; "13.56MHz NFC sticker" with no chip named is usually Mifare
Classic. 213/215/216 differ only in memory, which is irrelevant - this project
never writes to a tag, it reads the UID and nothing else. Avoid on-metal
(ferrite) tags, and avoid UID-changeable "magic" tags: unpredictable presence
is the exact failure this reader is most sensitive to.

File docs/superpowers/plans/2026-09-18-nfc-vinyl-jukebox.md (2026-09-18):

# NFC Vinyl Jukebox Implementation Plan

> **For agentic workers:** REQUIRED SUB-SKILL: Use superpowers-extended-cc:subagent-driven-development (recommended) or superpowers-extended-cc:executing-plans to implement this plan task-by-task. Steps use checkbox (`- [ ]`) syntax for tracking.

**Goal:** Build a Raspberry Pi NFC jukebox where placing a card plays an album and removing it stops playback, with audio to a local speaker and/or AirPlay 2 HomePods.

**Architecture:** OwnTone owns the music library, playback, and audio outputs (local ALSA + AirPlay 2 with PTP). A small Python service reads card presence from a PN532 over UART and drives OwnTone through its JSON REST API. A minimal web admin handles card registration only; everything player-related belongs to OwnTone's existing UI.

**Tech Stack:** Raspberry Pi 4 · Raspberry Pi OS Bookworm Lite 64-bit · OwnTone (apt) · Python 3.11 · nfcpy · httpx · Flask · pytest · systemd

**User decisions (already made):**
- "A is fine" — OwnTone as the engine with our own NFC daemon, not Phoniebox.
- "the idea is to simulate a vinyl functionality" — card on plays from track 1, card off stops.
- "Leave card on reader = plays; remove = pause."
- "No resume" — always start from the beginning.
- "why not just always output to both? web page is fine, we want the flexibility but it will 'live' in one mode."
- "so long as output actually sticks" — output persistence is an explicit acceptance criterion.
- "skipping would be in owntone's ui anyway" — build no transport controls.
- "None — cards only, volume from HomePod/phone" — no GPIO buttons, encoder, or LED.
- "we will be using all local flac files" — local files only, no Spotify.
- "can always be local if that's a constraint, it's fine" — local storage, no NAS mount.
- "let's name the repo owntone-nfc."

**Reference:** `docs/superpowers/specs/2026-09-18-nfc-vinyl-jukebox-design.md`

---

## File Structure

| File | Responsibility |
|---|---|
| `src/nfc_jukebox/owntone.py` | Thin OwnTone REST client. Knows nothing about cards. |
| `src/nfc_jukebox/cards.py` | Load/save `cards.yaml`, normalise UIDs. Knows nothing about playback. |
| `src/nfc_jukebox/outputs.py` | Output snapshot persistence (save/load selected output IDs to disk). |
| `src/nfc_jukebox/reader.py` | nfcpy wrapper emitting `card_present(uid)` / `card_removed()`. Plus `FakeReader` for tests. |
| `src/nfc_jukebox/controller.py` | The vinyl state machine. The only interesting logic; fully unit tested. |
| `src/nfc_jukebox/web.py` | Flask admin: learn mode, mapping table, status. |
| `src/nfc_jukebox/config.py` | Typed settings loaded from `/etc/nfc-jukebox/config.yaml`. |
| `src/nfc_jukebox/__main__.py` | Wires reader + controller + web together; entrypoint. |
| `deploy/nfc-jukebox.service` | systemd unit. |
| `deploy/owntone.conf.example` | Reference OwnTone config. |
| `docs/runbook.md` | Spike results, hardware settings, recovery steps. |

Split by responsibility, not layer. `controller.py` is the only file that knows both about cards and about playback.

---

## Phase 1 — Hardware and OS (Tasks 0–3)

### Task 0: Burn and boot the OS

**Goal:** A headless Pi 4 running Raspberry Pi OS Bookworm Lite 64-bit, reachable over SSH.

**Files:**
- Create: `docs/runbook.md`

**Acceptance Criteria:**
- [ ] `ssh jukebox.local` succeeds from the Mac without a password prompt
- [ ] `cat /etc/os-release` shows `VERSION_CODENAME=bookworm`
- [ ] `uname -m` prints `aarch64`

**Verify:** `ssh jukebox.local 'cat /etc/os-release | grep VERSION_CODENAME && uname -m'` → `VERSION_CODENAME=bookworm` and `aarch64`

**Steps:**

- [ ] **Step 1: Install Raspberry Pi Imager on the Mac**

```bash
brew install --cask raspberry-pi-imager
```

- [ ] **Step 2: Choose the correct OS image**

In Imager: *Choose Device* → Raspberry Pi 4. *Choose OS* → **Raspberry Pi OS (other)** → **Raspberry Pi OS Lite (64-bit)**.

**This must say Bookworm.** Imager now defaults to Trixie. If the Lite 64-bit entry shows Trixie, scroll to the bottom of the OS list and pick **Raspberry Pi OS (Legacy, 64-bit) Lite** — the Bookworm release. Bookworm is chosen for PN532 library maturity; see the spec.

- [ ] **Step 3: Configure via the Imager gear icon before writing**

Set: hostname `jukebox`, enable SSH with public-key authentication (paste `~/.ssh/id_ed25519.pub`), username `pi`, Wi-Fi SSID/password, locale/timezone.

- [ ] **Step 4: Write the image, boot the Pi, and connect**

```bash
ssh pi@jukebox.local
```

- [ ] **Step 5: Update packages**

```bash
sudo apt update && sudo apt full-upgrade -y && sudo reboot
```

- [ ] **Step 6: Record the result in the runbook**

```bash
cat > docs/runbook.md <<'EOF'
# Jukebox Runbook

## Hardware
- Raspberry Pi 4
- PN532 NFC HAT (DIP switches: UART)
- Audio: onboard 3.5mm (initial)

## OS
- Raspberry Pi OS Bookworm Lite 64-bit
- Hostname: jukebox.local, user: pi

## Spike results
(filled in by Tasks 4-6)
EOF
```

- [ ] **Step 7: Commit**

```bash
git add docs/runbook.md
git commit -m "docs: add runbook with OS and hardware baseline"
```

---

### Task 1: Configure UART for the PN532

**Goal:** The PL011 UART is available at `/dev/ttyAMA0` with no login console on it, so nfcpy can talk to the PN532.

**Files:**
- Modify: `/boot/firmware/config.txt` (on the Pi)
- Modify: `/boot/firmware/cmdline.txt` (on the Pi)
- Modify: `docs/runbook.md`

**Acceptance Criteria:**
- [ ] `/dev/ttyAMA0` exists
- [ ] No `getty` process is attached to `ttyAMA0`
- [ ] `cmdline.txt` contains no `console=serial0` entry
- [ ] The `pi` user is in the `dialout` group

**Verify:** `ssh jukebox.local 'ls -l /dev/ttyAMA0; systemctl is-enabled serial-getty@ttyAMA0.service; groups pi'` → device exists, getty reports `masked` or `disabled`, groups include `dialout`

**Steps:**

- [ ] **Step 1: Set the PN532 HAT DIP switches to UART mode**

Physical step. On a Waveshare PN532 HAT the switches are labelled for I2C / SPI / UART — set UART. Power the Pi off before changing them.

We use UART rather than I2C because **nfcpy supports the PN532 over serial and USB but not I2C**, and nfcpy is the library with a real card-presence API. Presence detection is the whole design.

- [ ] **Step 2: Disable the serial console**

```bash
sudo raspi-config nonint do_serial_hw 0
sudo raspi-config nonint do_serial_cons 1
```

`do_serial_hw 0` enables the serial port hardware; `do_serial_cons 1` disables the login shell over serial.

- [ ] **Step 3: Move the PL011 UART to the GPIO header**

```bash
echo 'dtoverlay=disable-bt' | sudo tee -a /boot/firmware/config.txt
sudo systemctl disable hciuart
```

Without this, GPIO14/15 get the mini-UART, whose baud rate is tied to the VPU clock and drifts. `disable-bt` gives up onboard Bluetooth — which costs nothing in this design — and hands the good PL011 to the header. Wi-Fi is unaffected.

- [ ] **Step 4: Grant serial access and reboot**

```bash
sudo usermod -aG dialout pi
sudo reboot
```

- [ ] **Step 5: Verify**

```bash
ssh jukebox.local 'ls -l /dev/ttyAMA0 && groups pi'
```

Expected: `/dev/ttyAMA0` listed with group `dialout`, and `pi` in the `dialout` group.

- [ ] **Step 6: Record in the runbook and commit**

Append to `docs/runbook.md`:

```markdown
## UART
- PN532 HAT DIP switches: UART
- dtoverlay=disable-bt (PL011 on GPIO14/15, onboard Bluetooth given up)
- serial console disabled; device is /dev/ttyAMA0
```

```bash
git add docs/runbook.md
git commit -m "docs: record UART configuration for PN532"
```

---

### Task 2: Music storage and Samba share

**Goal:** `/srv/music` exists on the SD card with `<Artist>/<Album>` layout, seeded with a subset of the library, writable from the Mac over Samba.

**Files:**
- Modify: `/etc/samba/smb.conf` (on the Pi)
- Modify: `docs/runbook.md`

**Capacity note.** The full library is ~56GB of FLAC; a 64GB card gives ~59.6GiB usable
and the OS takes ~2.5GB. That leaves under 1GB of headroom, and a near-full filesystem
will corrupt OwnTone's SQLite database. **So: seed a subset now (target ≤ 20GB) and
prove the system.** Two ways out later, both supported and neither requiring cards to be
re-registered: a larger SD card (Task 14), or mounting the NAS (Task 15).

**Acceptance Criteria:**
- [ ] `/srv/music` exists, owned by `pi`
- [ ] The share mounts from macOS Finder at `smb://jukebox.local/music`
- [ ] At least 5 albums present under `<Artist>/<Album>/`
- [ ] `df -h /` shows at least 20GB free after copying

**Verify:** `ssh jukebox.local 'ls /srv/music && df -h / | tail -1'` → artist directories listed, ≥20GB available

**Steps:**

- [ ] **Step 1: Create the library root**

```bash
sudo mkdir -p /srv/music
sudo chown -R pi:pi /srv/music
```

Layout is `/srv/music/<Artist>/<Album>/`. This matters more than it looks: card mappings
key off the album path prefix, which is what makes them survive a rebuild onto a new SD
card. OwnTone's numeric library IDs would not.

`/srv/music` is a *library root*, not necessarily a local directory — Task 15 can turn it
into a NAS mount without touching a single card mapping, because mappings store paths
relative to this root.

- [ ] **Step 2: Install and configure Samba**

```bash
sudo apt install -y samba
sudo tee -a /etc/samba/smb.conf <<'EOF'

[music]
   path = /srv/music
   browseable = yes
   read only = no
   force user = pi
EOF
sudo smbpasswd -a pi
sudo systemctl restart smbd
```

- [ ] **Step 3: Copy a subset of albums from the Mac**

In Finder: *Go → Connect to Server* → `smb://jukebox.local` → `music`. Copy **5–10 albums**
(≤20GB total) preserving `<Artist>/<Album>/` structure. Pick albums you will actually
map to cards in Task 15, so the end-to-end test is real.

- [ ] **Step 4: Verify capacity and layout**

```bash
ssh jukebox.local 'find /srv/music -mindepth 2 -maxdepth 2 -type d | head && df -h /'
```

Expected: album directories listed, and the root filesystem showing ≥20GB available.

- [ ] **Step 5: Record in the runbook and commit**

Append to `docs/runbook.md`:

```markdown
## Music storage
- /srv/music on the SD card, layout <Artist>/<Album>/
- Currently a SUBSET of the ~56GB library (64GB card cannot hold it all)
- Larger card migration: see deploy/provision.sh and Task 14
```

```bash
git add docs/runbook.md
git commit -m "docs: record music storage layout and Samba share"
```

### Task 3: Install and configure OwnTone

**Goal:** OwnTone is running from its apt repo, has scanned `/srv/music`, and its web UI is reachable.

**Files:**
- Create: `deploy/owntone.conf.example`
- Modify: `docs/runbook.md`

**Acceptance Criteria:**
- [ ] `systemctl is-active owntone` returns `active`
- [ ] `http://jukebox.local:3689` loads the OwnTone web UI
- [ ] `GET /api/library` reports a non-zero track count
- [ ] Local ALSA output appears in `GET /api/outputs`

**Verify:** `curl -s http://jukebox.local:3689/api/library | python3 -m json.tool | grep songs` → non-zero `songs` count

**Steps:**

- [ ] **Step 1: Add the OwnTone apt repository**

```bash
wget -q -O - https://raw.githubusercontent.com/owntone/owntone-apt/refs/heads/master/repo/rpi/owntone.gpg \
  | sudo gpg --dearmor --output /usr/share/keyrings/owntone-archive-keyring.gpg
sudo wget -q -O /etc/apt/sources.list.d/owntone.list \
  https://raw.githubusercontent.com/owntone/owntone-apt/refs/heads/master/repo/rpi/owntone-bookworm.list
sudo apt update && sudo apt install -y owntone
```

We install from apt rather than building from source (as the Instructables build did) because apt gives us upgrades for free.

- [ ] **Step 2: Configure OwnTone**

```bash
sudo tee /etc/owntone.conf >/dev/null <<'EOF'
general {
        uid = "owntone"
        admin_password = ""
        ipv6 = no
}

library {
        name = "Jukebox"
        port = 3689
        directories = { "/srv/music" }
        follow_symlinks = true
}

audio {
        nickname = "Local"
        type = "alsa"
        card = "default"
}
EOF
sudo systemctl restart owntone
```

`ipv6 = no` is deliberate: OwnTone's own troubleshooting docs note that some speakers advertise IPv6 support but then fail to play over it.

- [ ] **Step 3: Confirm the library scanned**

```bash
curl -s http://jukebox.local:3689/api/library | python3 -m json.tool
```

Expected: a JSON object with a non-zero `songs` value.

- [ ] **Step 4: Confirm local audio output**

```bash
curl -s http://jukebox.local:3689/api/outputs | python3 -m json.tool
```

Expected: an output with `"type": "alsa"` and `"name": "Local"`.

- [ ] **Step 5: Save the reference config and commit**

```bash
mkdir -p deploy
ssh jukebox.local 'cat /etc/owntone.conf' > deploy/owntone.conf.example
git add deploy/owntone.conf.example docs/runbook.md
git commit -m "feat: add OwnTone reference configuration"
```

---

## Phase 2 — Spikes (Tasks 4–6)

These run before any application code exists. They are deliberately first: each one can
invalidate a design assumption, and finding that out now costs an evening instead of a
rewrite.

### Task 4: Spike 0 — prove the AirPlay send path (Mac first, then HomePods)

**Goal:** Prove OwnTone can select and play to an AirPlay 2 receiver — staged: the Mac as a positive control, then the HomePod stereo pair.

> **USER-ORDERED GATE — NON-SKIPPABLE.** This task was requested by the user in the current conversation. It MUST NOT be closed by walking around it, by declaring it "verified inline", or by substituting a cheaper check. Close only after every item in `acceptanceCriteria` has been re-validated independently, with output captured.

**Files:**
- Modify: `docs/runbook.md`

**Why this is the gate.** Standalone HomePods and stereo pairs are well-proven with
OwnTone. HomePods **bound to an Apple TV as home-theater speakers** are not covered in
OwnTone's docs, and the one builder who documented a Phoniebox+HomePod setup reported
exactly this configuration as the case that failed. Every remaining task assumes AirPlay
output works.

**Why stage it through the Mac.** Testing against the Mac separates "can OwnTone send
AirPlay at all" from "will this particular Apple TV / HomePod arrangement cooperate" —
two failures that look identical from the Pi. It also keeps the HomePods quiet during
development.

**Why the Mac rather than shairport-sync.** shairport-sync is a third-party
reimplementation of AirPlay; the Mac runs Apple's own AirPlay 2 receiver stack, the same
lineage as the HomePod. A pass against the Mac carries real information about HomePod
compatibility; a pass against shairport-sync mostly tests shairport-sync. Install it
later if a permanently silent sink is wanted, but do not make it the gate.

**Read the stages asymmetrically.** A Mac success proves the send path works end to end.
A Mac *failure* does **not** predict HomePod failure — they are different authentication
paths. Never abandon the design on a Stage A failure alone; always run Stage B.

**Acceptance Criteria:**
- [ ] **Stage A:** the Mac appears as an `airplay` output and plays audibly
- [ ] `GET /api/outputs` lists the HomePod pair as an output with `"type": "airplay"`
- [ ] Selecting that output and playing a track produces **audible sound from the HomePods**
- [ ] Playback survives 60 seconds without the output deselecting itself
- [ ] Deselecting the output releases the HomePods (they return to idle)
- [ ] The working configuration is written into `docs/runbook.md`

**Verify:** `curl -s http://jukebox.local:3689/api/outputs | python3 -m json.tool | grep -iA3 airplay` → HomePod output present with `"selected": true` during playback

**Steps:**

#### Stage A — the Mac as a positive control

- [ ] **Step A1: Configure the Mac's AirPlay receiver correctly**

*System Settings → General → AirDrop & Handoff → AirPlay Receiver*:

- **Allow AirPlay for: "Anyone on the Same Network"** — not "Current User". The Pi is not
  signed into your Apple ID, so "Current User" makes it invisible.
- **"Require password": OFF.** This is not optional. OwnTone cannot send an AirPlay
  password — [issue #1385](https://github.com/owntone/owntone-server/issues/1385), still
  open — and fails with a 500 and `requires a valid PIN or password` in the log. Leaving
  this on produces a failure that has nothing to do with your speakers.

- [ ] **Step A2: Turn the Mac's system volume down before anything plays**

Set it low but not muted — you need to hear *something* to confirm the path works.

- [ ] **Step A3: Confirm the Mac appears and plays**

```bash
curl -s http://jukebox.local:3689/api/outputs | python3 -m json.tool | grep -iB2 -A3 airplay
MAC=$(curl -s http://jukebox.local:3689/api/outputs \
  | python3 -c "import sys,json; print([o['id'] for o in json.load(sys.stdin)['outputs'] if o['type'].lower().startswith('airplay')][0])")
curl -s -X PUT -H 'Content-Type: application/json' \
  -d "{\"outputs\":[\"$MAC\"]}" http://jukebox.local:3689/api/outputs/set
curl -s -X POST "http://jukebox.local:3689/api/queue/items/add?expression=media_kind+is+music&limit=1&clear=true&playback=start"
```

Expected: audible music from the Mac's speakers. Approve the pairing prompt if one
appears — the Mac raises one on each reconnect, which is normal and not a HomePod signal.

- [ ] **Step A4: Record the outcome**

If Stage A passes, the OwnTone AirPlay send path is proven and any Stage B failure is
specific to the Apple TV / HomePod arrangement. Note that distinction in the runbook —
it is what tells you which fallback to reach for.

#### Stage B — the HomePods

**Never blast the HomePods.** Output volume is settable *before* playback starts and is
independent of the queue, so every Stage B test begins by turning the target down. This
is the point of Step 2 below — do not skip it and "just be quick".

- [ ] **Step 1: Fix the Apple-side permission FIRST**

In the **Home app** on iPhone: *Home Settings → Allow Speakers & TV Access → **Anyone On
the Same Network***.

Do this before diagnosing anything else. Apple's default is *"Only People Sharing This
Home,"* which a Linux sender cannot satisfy. The symptom is that the speaker **deselects
itself the instant playback starts**, with `ANNOUNCE request failed in session startup:
400 Bad Request` in the log. It looks exactly like a compatibility failure but is a
permissions one, and it is the most likely cause of the prior builder's reported failure.

- [ ] **Step 2: Enumerate what is actually on the network**

```bash
sudo apt install -y python3-pip
pip3 install --break-system-packages pyatv
atvremote scan
```

This is faster than diagnosing through OwnTone's UI. Record whether the HomePods appear
individually, as a single pair, or only as the Apple TV.

- [ ] **Step 3: Check OwnTone's view**

```bash
curl -s http://jukebox.local:3689/api/outputs | python3 -m json.tool
```

Expected: an entry with `"type": "airplay"` named after the HomePod pair.

- [ ] **Step 4: Select the output, turn it DOWN, then play**

```bash
OUT=$(curl -s http://jukebox.local:3689/api/outputs \
  | python3 -c "import sys,json; print([o['id'] for o in json.load(sys.stdin)['outputs'] if o['type'].lower().startswith('airplay')][0])")
curl -s -X PUT -H 'Content-Type: application/json' \
  -d "{\"outputs\":[\"$OUT\"]}" http://jukebox.local:3689/api/outputs/set

# Turn the HomePods down BEFORE any audio is queued. Per-output volume is
# independent of playback state, so this cannot be "too early".
curl -s -X PUT -H 'Content-Type: application/json' \
  -d '{"volume": 5}' "http://jukebox.local:3689/api/outputs/$OUT"
curl -s -X POST "http://jukebox.local:3689/api/queue/items/add?expression=media_kind+is+music&limit=1&clear=true&playback=start"
```

Expected: audible music from the HomePods within a few seconds.

- [ ] **Step 5: Watch the log if it fails**

```bash
sudo journalctl -u owntone -f
```

Look for `ANNOUNCE request failed` (→ redo Step 1) or IPv6 errors (→ confirm
`ipv6 = no` in `/etc/owntone.conf`).

- [ ] **Step 6: If it still fails, work the fallbacks in order**

1. **PIN-pair the Apple TV as the target.** OwnTone web UI → *Settings → Remotes &
   Outputs* → select the Apple TV → enter the PIN it displays. Required for Apple TV4 /
   tvOS 10.2+.
2. **Un-bind the HomePods from the Apple TV** in the Home app so they become standalone
   AirPlay targets. This is the known-good configuration.

- [ ] **Step 7: Confirm release works**

```bash
curl -s -X PUT -H 'Content-Type: application/json' \
  -d '{"outputs":[]}' http://jukebox.local:3689/api/outputs/set
```

Expected: music stops and the HomePods return to idle, available to other senders.

- [ ] **Step 8: Record the outcome and commit**

Append to `docs/runbook.md` — which configuration worked, the AirPlay output's name and
id, and whether the Home app permission change was required.

```bash
git add docs/runbook.md
git commit -m "docs: record Spike 0 HomePod reachability results"
```

```json:metadata
{"userGate": true, "tags": ["user-gate", "spike"], "gateScope": "blocks-all-downstream", "verifyCommand": "curl -s http://jukebox.local:3689/api/outputs | python3 -m json.tool", "acceptanceCriteria": ["Stage A: Mac plays audibly as an airplay output", "airplay output listed for HomePods", "audible sound from HomePods", "survives 60s without deselecting", "deselect releases the HomePods", "config recorded in runbook"], "requireEvidenceTokens": [["stage-a", "mac-receiver"], ["stage-b", "homepod"]], "modelTier": "standard"}
```

---

### Task 5: Spike 1 — queue an album by relative path

**Goal:** Confirm against a live server the OwnTone `expression` syntax that queues one album, in correct track order, from a library-root-relative path.

> **Updated after source verification.** The grammar was checked against OwnTone's
> smart-playlist lexer (`src/parsers/smartpl_lexer.l`): `path`, `includes`,
> `starts with`, `order by`, `asc`/`desc` are valid tokens, and the integer tags are
> **`disc`** and **`track`** — *not* `disc_number`/`track_number`, which are JSON-API
> field names and would have failed to parse, returning 400 on every card tap.
> The code now uses the verified spelling. This spike confirms it against a running
> server, which source-reading cannot substitute for.

**Files:**
- Modify: `docs/runbook.md`

**Why this matters.** Card mappings store relative paths rather than numeric
`library:album:<id>` values, because numeric IDs are assigned at scan time and differ on
every rebuild — they would break every mapping on a new SD card. This spike verifies the
syntax, not the decision.

**Acceptance Criteria:**
- [ ] A single `POST /api/queue/items/add` call queues exactly one album's tracks
- [ ] Tracks are in disc/track order, not filesystem or alphabetical order
- [ ] No tracks from other albums appear in the queue
- [ ] The verified expression string is recorded in `docs/runbook.md`

**Verify:** `curl -s http://jukebox.local:3689/api/queue | python3 -c "import sys,json; q=json.load(sys.stdin)['items']; print(len(q)); [print(t['track_number'], t['title']) for t in q]"` → count matches the album, numbers ascending from 1

**Steps:**

- [ ] **Step 1: Pick a test album and clear the queue**

```bash
ALBUM="Miles Davis/Kind of Blue"   # replace with a real album from Task 2
# Note the trailing slash: the code anchors the match so that a card mapped to
# "Rumours" cannot also sweep in "Rumours (Deluxe)".
curl -s -X PUT http://jukebox.local:3689/api/queue/clear
```

- [ ] **Step 2: Try the primary expression**

```bash
curl -s -G -X POST http://jukebox.local:3689/api/queue/items/add \
  --data-urlencode "expression=path includes \"$ALBUM/\" order by disc asc, track asc" \
  --data-urlencode "clear=true"
```

- [ ] **Step 3: Inspect the queue**

```bash
curl -s http://jukebox.local:3689/api/queue \
  | python3 -c "import sys,json; q=json.load(sys.stdin)['items']; print(len(q),'tracks'); [print(t.get('disc_number'), t.get('track_number'), t['title']) for t in q]"
# NB: disc_number/track_number ARE correct here - these are JSON-API track
# objects. Only the *expression grammar* uses disc/track. Confusing the two is
# what caused the original bug.
```

Expected: the album's track count, ascending track numbers, nothing foreign.

- [ ] **Step 4: If ordering is wrong, try without the order clause**

```bash
curl -s -X PUT http://jukebox.local:3689/api/queue/clear
curl -s -G -X POST http://jukebox.local:3689/api/queue/items/add \
  --data-urlencode "expression=path includes \"$ALBUM\"" \
  --data-urlencode "clear=true"
```

Then re-inspect. If OwnTone already returns track order by default, the simpler
expression wins.

- [ ] **Step 5: If `includes` is rejected, try `starts with`**

```bash
curl -s -G -X POST http://jukebox.local:3689/api/queue/items/add \
  --data-urlencode "expression=path starts with \"/srv/music/$ALBUM\"" \
  --data-urlencode "clear=true"
```

Note this variant needs the absolute path, so the code must join the library root before
querying. Record which variant worked — Task 8 encodes it in one constant.

- [ ] **Step 6: Record the verified expression and commit**

Append to `docs/runbook.md`:

```markdown
## Spike 1 result
Verified album expression (used by ALBUM_EXPRESSION in owntone.py):
    <paste the exact working expression string here>
Requires absolute path: yes/no
```

```bash
git add docs/runbook.md
git commit -m "docs: record Spike 1 verified album expression syntax"
```

---

### Task 6: Spike 2 — PN532 presence polling and bump-window measurement

**Goal:** Prove nfcpy gives stable continuous card-presence detection over UART, and measure the real dropped-read rate to set the bump window.

**Files:**
- Create: `spikes/presence_check.py`
- Modify: `docs/runbook.md`

**Why measure rather than guess.** The bump window decides whether a returning card
resumes or restarts. Too short and a momentary dropped read restarts the album; too long
and a deliberate lift-and-replace wrongly resumes. Phoniebox's equivalent setting has a
minimum of 0.2s, chosen specifically to ride out brief missed reads — so the real answer
is expected to be sub-second, not the several seconds originally guessed.

**Acceptance Criteria:**
- [ ] The script reports card arrival within 500ms of placing a card
- [ ] It reports removal within 500ms of lifting a card
- [ ] Over a 5-minute run with a card left stationary, the observed dropped-read gaps are recorded
- [ ] A bump-window value is chosen as `max(observed gap) * 2`, rounded up, and recorded

**Verify:** `ssh jukebox.local 'cd ~/owntone-nfc && python3 spikes/presence_check.py --duration 300'` → prints arrival/removal events and a max-gap summary

**Steps:**

- [ ] **Step 1: Install nfcpy on the Pi**

```bash
sudo apt install -y python3-venv
python3 -m venv ~/jukebox-venv
~/jukebox-venv/bin/pip install nfcpy
```

- [ ] **Step 2: Write the spike script**

```python
# spikes/presence_check.py
"""Measure PN532 card-presence stability over UART.

Prints arrival/removal events and, for a stationary card, the largest gap
between successful presence reads. That gap sets the bump window.
"""
import argparse
import time

import nfc

DEVICE = "tty:AMA0:pn532"
POLL_INTERVAL = 0.05

def main() -> None:
    parser = argparse.ArgumentParser()
    parser.add_argument("--duration", type=float, default=300.0)
    args = parser.parse_args()

    clf = nfc.ContactlessFrontend(DEVICE)
    print(f"Reader open on {DEVICE}. Place a card and leave it.")

    deadline = time.monotonic() + args.duration
    max_gap = 0.0

    try:
        while time.monotonic() < deadline:
            tag = clf.connect(rdwr={"on-connect": lambda tag: False})
            if tag is None:
                continue
            uid = tag.identifier.hex()
            arrived = time.monotonic()
            print(f"[{arrived:10.3f}] PRESENT {uid}")

            last_seen = time.monotonic()
            while tag.is_present:
                now = time.monotonic()
                gap = now - last_seen
                max_gap = max(max_gap, gap)
                last_seen = now
                time.sleep(POLL_INTERVAL)

            removed = time.monotonic()
            print(f"[{removed:10.3f}] REMOVED {uid} after {removed - arrived:.2f}s")
    except KeyboardInterrupt:
        pass
    finally:
        clf.close()

    print(f"\nMax gap between presence reads: {max_gap:.3f}s")
    print(f"Suggested bump window: {max(0.2, max_gap * 2):.2f}s")

if __name__ == "__main__":
    main()
```

- [ ] **Step 3: Run it and exercise the reader**

```bash
~/jukebox-venv/bin/python spikes/presence_check.py --duration 300
```

While it runs: place a card and leave it for several minutes, then lift and replace it a
few times at different speeds.

Expected: `PRESENT` within ~0.5s of placement, `REMOVED` within ~0.5s of lifting, and a
max gap well under 1s.

- [ ] **Step 4: If the reader does not open at all**

```bash
ls -l /dev/ttyAMA0        # device must exist (Task 1)
groups                    # must include dialout
```

If the device is missing, re-check the HAT DIP switches are on UART and that
`dtoverlay=disable-bt` is in `/boot/firmware/config.txt`.

- [ ] **Step 5: Record the measured value and commit**

Append to `docs/runbook.md`:

```markdown
## Spike 2 result
Max observed gap between presence reads: <value>s
Chosen bump_window_s: <value>
Chosen grace_period_s: 90 (design default)
```

```bash
git add spikes/presence_check.py docs/runbook.md
git commit -m "feat: add PN532 presence spike and record measured bump window"
```

---

## Phase 3 — Application (Tasks 7–14)

Written test-first. `controller.py` is the only file with non-trivial logic, so it gets
the bulk of the tests; everything else stays thin enough to be obviously correct.

### Task 7: Project scaffolding and configuration

**Goal:** An installable Python package with pytest wired up and a typed config object.

**Files:**
- Create: `pyproject.toml`
- Create: `src/nfc_jukebox/__init__.py`
- Create: `src/nfc_jukebox/config.py`
- Create: `tests/__init__.py` (empty — makes `tests` importable, required by Task 14)
- Create: `tests/test_config.py`

**Acceptance Criteria:**
- [ ] `pytest` runs and collects tests
- [ ] `Config.load()` reads a YAML file and returns typed values
- [ ] Missing config file yields documented defaults rather than an exception

**Verify:** `pytest tests/test_config.py -v` → 3 passed

**Steps:**

- [ ] **Step 1: Write `pyproject.toml`**

```toml
[project]
name = "nfc-jukebox"
version = "0.1.0"
requires-python = ">=3.11"
dependencies = [
    "httpx>=0.27",
    "PyYAML>=6.0",
    "Flask>=3.0",
    "nfcpy>=1.0",
]

[project.optional-dependencies]
dev = ["pytest>=8.0", "respx>=0.21"]

[build-system]
requires = ["setuptools>=68"]
build-backend = "setuptools.build_meta"

[tool.setuptools.packages.find]
where = ["src"]

[tool.pytest.ini_options]
testpaths = ["tests"]
pythonpath = ["src"]
```

- [ ] **Step 2: Write the failing test**

```python
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

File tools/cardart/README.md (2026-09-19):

# Card artwork

Collects print-resolution cover art for albums that don't have a card yet,
so new records can be turned into cards without hunting for images by hand.

## Running it

```sh
./refresh.sh
```

That's the whole loop. It fetches artwork for every album the jukebox reports
as unassigned, copies the results to `~/Documents/_Personal/music/cardart/`,
and opens a review sheet.

Re-run it whenever you add music. Work already done is cached, so a second run
only touches albums that are new, that failed last time, or whose override you
have edited. `--refetch` starts over from scratch.

The fetching runs on the Pi, because that is where the music is: artwork
already in the library is preferred over anything downloaded, and it can only
be read there.
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

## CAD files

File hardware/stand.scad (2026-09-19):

// Jukebox stand -- a card sits in it the way a record sits on a hi-fi shelf.
//
// Design intent: this lives in a room, next to speakers, with album art on
// the front. It should read as a made object, not a printed bracket. So:
//
//   * every visible edge is chamfered, and the vertical corners are radiused,
//     so the form catches light along its arrises instead of showing a raw
//     printed corner;
//   * a shadow reveal runs round the base, which lifts the body optically and
//     hides the one joint where a print's first layers look worst;
//   * the card drops into a slot in a full-width rail rather than leaning on
//     an applied shelf, so the front is two clean horizontal lines;
//   * a thumb scoop in the rail lets you lift a card out without scratching
//     the art or clawing at the edge;
//   * the back is open, so the Pi's ports are simply reachable -- no cutouts
//     to misalign, no internal extension cables, and ventilation for free.
//
//   openscad -o coupon.stl -D 'part="coupon"' stand.scad   // print FIRST
//   openscad -o stand.stl  stand.scad
//
// ---------------------------------------------------------------------------
// MEASURE BEFORE PRINTING THE STAND.
// window_t is the only dimension that can quietly ruin this: too thick and the
// reader stops seeing 4-byte cards -- and it fails as intermittent flapping
// rather than an honest "no read", which is far harder to diagnose once it is
// assembled. Print the coupon, test with your worst card, watch the presence
// cycle count rather than whether it reads at all.
// ---------------------------------------------------------------------------

part = "stand";

/* [Card] */
card       = 95;      // printed card, mm square
card_t     = 1.6;     // slot width: card plus a little, so it drops in
lean       = 14;      // face angle from vertical

/* [Proportions] */
side_margin = 12.5;   // face material either side of the card
top_margin  = 12;     // above the card
lip_h       = 11;     // the lip the card stands on
depth       = 66;
back_h      = 0.74;   // side walls' height at the back, as a fraction of the
                      // front. Lower looks lighter; too low and the Pi and the
                      // whole cavity are on show from the side.

/* [Detail] */
corner_r   = 5;       // radius on the vertical corners
// No shadow reveal round the base. There was one, to lift the body optically,
// but the lip covers it across the front -- so it ran three-quarters of the
// way round and stopped, which reads as a mistake rather than a detail. The
// lip already gives the front its horizontal line.
chamfer    = 1.2;     // on every visible edge
taper      = 9;       // how far the sides rake in, per side, bottom to top
lip_depth  = 9;       // how far the lip projects from the face
lip_face   = 3.5;     // height of the lip's own front face, above its chamfer
// The lip ends exactly where the body's corner arc begins, and curves back
// with the same radius to meet it. The body's front is flat across
// +/-(width/2 - corner_r); beyond that it is turning. Run the lip any wider
// and it projects past a face that is already curving away, which is what left
// a tab at the corner. Any narrower and it stops short for no reason.
// The 0.4 is not decoration: ending exactly on the tangent point means the
// lip's end arc and the body's corner arc touch at a single line, and CGAL
// turns that into non-manifold edges. A hair short of it, they overlap
// properly. Invisible in plastic, the difference between a valid mesh and one
// a slicer refuses.
lip_inset  = corner_r + 0.4;
lip_return = 15;      // radius the lip's ends sweep back on, dying into the
                      // face. Much larger than corner_r on purpose: at the
                      // body's own 5mm the lip stopped rather than returned,
                      // and its flat end ran straight into the face. A long
                      // sweep reads as one S from the body's curve into the
                      // lip's.
concave_r  = 0.9;     // softens the crease where the lip's top meets the face
lip_fillet = 5;       // cove where the lip's ends run into the face
felt_inset = 1.5;     // felt recess held back from the front edge
// The felt recess runs from felt_inset all the way BACK INTO the panel,
// leaving no wall behind it. There used to be 1.5mm of shelf between the
// recess and the face, and it was not only a fussy little ridge to look at --
// the card's bottom edge would have had to sit on top of it, holding the card
// off the face it is supposed to lean against.
felt_w     = lip_depth - felt_inset + 0.6;
felt_t     = 1.2;

/* [Shell] */
face_t     = 3.2;     // panel thickness
// Thinned panel over the coil. Equal to face_t = no thinning, which is the
// right default here: with the HAT on ~11mm standoffs the coil is ~14mm from
// the card, so the panel is a small part of the gap and thinning it only
// leaves a weak patch behind the card for nothing. Drop it to ~1.2 only in the
// close-mounted variant, where the HAT nearly touches the panel.
window_t   = 3.2;
wall       = 3;
base_t     = 4;

/* [Raspberry Pi 4] */
pi_w = 85; pi_h = 56;
pi_hole_dx = 58; pi_hole_dy = 49;
standoff_d = 6.4; screw_d = 2.3;

// You screw the HAT to the face, not the Pi. They share the 85 x 56 footprint
// and the same hole pattern, and the coil has to be the thing nearest the
// card: with the Pi against the panel instead, the HAT ends up behind it on
// the GPIO header, ~20mm further away and with the Pi's ground planes in the
// way. The Pi then hangs off the back of the HAT on that header.
//
// The height is set by the HAT's own tall top-side parts -- the 1x17 breakout
// and the 2x3 jumper block stand 7.6mm proud of the board (measured from
// Waveshare's STEP model) -- and they face the panel in this orientation.
//
// Note what that means: at 11mm the coil sits ~14mm behind the card, so the
// STANDOFF is the read gap and the thinned window buys nothing. Getting the
// coil close enough to matter needs a relief opening in the panel for those
// headers, which the card would hide. Measure first with the gauge below.
//
// Each boss is a full-height CONE rather than a post.
//
// A plain cylinder projecting from this face is a 90-degree overhang at its
// root -- its first layers have nothing under them, which is exactly the
// "floating" it looks like in a render. Tapering the whole boss at 45 degrees
// means every layer lands on the one below: the face leans back 14 degrees, so
// the boss axis points 14 degrees below horizontal and the cone's underside
// ends up 31 degrees from vertical, well inside what prints unsupported.
//
// A cone is also far stiffer at the root than a post of the same height, which
// is where the screw load goes. No hardware, no supports, one part.
//
// Printing the whole stand face-down would give vertical bosses and a better
// show face, but it buries the lip in the bed -- and the lip carries the
// card's weight every time, so that is the wrong place for a glued joint.
standoff_h = 11;

/* [PN532 HAT antenna] */
// Measured from Waveshare's own dimension drawing for the PN532 NFC HAT
// (files.waveshare.com, "PN532-NFC-HAT-size.jpg"): the board is 85 x 56 mm --
// the same footprint as the Pi, not a short 65mm HAT -- and the coil panel is
// 37.4 x 37.8 mm, centred 17.0 mm along the long axis and 2.3 mm across from
// the board's centre, on the far side from the GPIO header.
hat_ant_dx = 17.0;
hat_ant_dy = 2.3;
ant_w      = 42;      // window a little larger than the 37.4mm panel
ant_h      = 42;

// Turning the HAT end-for-end in the stand mirrors that offset, which is
// usually what decides whether the coil can reach the tag at all.
hat_flipped = false;

/* [Where the tag sits on the card] */
// Centre of the tag relative to the centre of the card, seen from the FRONT,
// +x right and +y up.
//
// Measured on these cards from the BACK: 30mm in from the left edge, 65mm down
// from the top. Viewing from the front mirrors left to right but not top to
// bottom, so that is 65mm from the left and 65mm from the top -- the lower
// RIGHT quadrant from the front, however it looks from behind.
tag_dx = 17.5;
tag_dy = -17.5;

$fn = 64;

// --- derived -----------------------------------------------------------
// The coil must land on the tag, so the tag's position drives where the Pi
// goes -- not the reverse. ant_dx/ant_dy are the coil's position in the face's
// frame; pi_dx/pi_dy are where the board centre must sit to put it there.
ant_dx = tag_dx;
ant_dy = tag_dy;
pi_dx  = tag_dx - (hat_flipped ? -hat_ant_dx : hat_ant_dx);
pi_dy  = tag_dy - (hat_flipped ? -hat_ant_dy : hat_ant_dy);
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

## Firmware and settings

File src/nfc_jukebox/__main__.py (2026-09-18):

# src/nfc_jukebox/__main__.py
"""Wire reader, controller and web admin together."""
from __future__ import annotations

import logging
import threading
import time

from .cards import CardStore
from .config import Config
from .controller import Controller
from .outputs import OutputSnapshot
from .owntone import OwnTone
from .reader import Pn532Reader
from .web import create_app

TICK_INTERVAL = 1.0


def main() -> None:
    logging.basicConfig(level=logging.INFO,
                        format="%(asctime)s %(levelname)s %(name)s %(message)s")
    # The admin page polls /api/status every second, so werkzeug's access log
    # writes a line per second forever. On a box that runs for months that
    # buries the errors worth reading. Warnings and above still come through.
    logging.getLogger("werkzeug").setLevel(logging.WARNING)
    log = logging.getLogger("nfc_jukebox")

    config = Config.load()
    store = CardStore(config.cards_file)
    owntone = OwnTone(config.owntone_url)
    controller = Controller(
        owntone=owntone,
        cards=store,
        snapshot=OutputSnapshot(config.outputs_file),
        config=config,
    )

    reader = Pn532Reader(config.reader_device, reset_gpio=config.reset_gpio,
                         presence_debounce_s=config.presence_debounce_s)
    reader.on_present = controller.on_card_present
    reader.on_removed = controller.on_card_removed

    app = create_app(config, controller, store, owntone=owntone)
    threading.Thread(
        target=lambda: app.run(host="0.0.0.0", port=config.web_port,
                               threaded=True, use_reloader=False),
        daemon=True,
    ).start()

    def tick_forever() -> None:
        while True:
            try:
                controller.tick()
            except Exception:
                log.exception("Tick failed")
            time.sleep(TICK_INTERVAL)

    threading.Thread(target=tick_forever, daemon=True).start()

    log.info("Reader open on %s", config.reader_device)
    reader.run()


if __name__ == "__main__":
    main()

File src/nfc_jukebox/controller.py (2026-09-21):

"""The vinyl state machine.

Put the record on and it plays. Take it off and it pauses - lifting a card is
how you pause a record player, and pausing must not lose your place. The record
stays on the platter until a different one is put on: the same card always
resumes, a different card clears the queue and starts from track 1, and an
album that plays out to its end leaves no place to hold.

The grace period exists because AirPlay 2's PTP handshake costs a couple of
seconds, so the session is held through short gaps and the speakers are handed
back only when the user is genuinely done. That release now deselects the
outputs *without* stopping or clearing the queue, which is what keeps the
position alive across it.

Two time sources, deliberately. Every duration - the grace period, the polling
intervals - is measured on a monotonic clock, so an NTP step cannot strand a
paused card or fire a release an hour early. The nightly resume reset is the
one question a monotonic clock cannot answer ("has 3am happened yet?"), so it,
and only it, reads a wall clock.
"""
from __future__ import annotations

import datetime
import enum
import logging
import threading
import time
from contextlib import contextmanager
from typing import Callable, Iterator

from .cards import normalise_uid

log = logging.getLogger(__name__)

# How often, while an album is playing, to ask OwnTone whether the outputs we
# asked for are still the outputs it is using.
#
# Not every tick: tick() runs once a second for as long as the box is powered
# on, and a per-tick check would be two HTTP round trips a second, forever, to
# watch for something that happens once at the start of a record. Not at card
# tap either: the AirPlay 2 failure this exists to catch lands *after* every
# synchronous call has returned success, and the tap path is already ~3s of
# latency that must not grow.
#
# 10s is chosen from the failure's own timing: OwnTone's pairing attempt and
# the self-deselect that follows it play out over a few seconds, so the first
# check lands after the dust settles, and the operator learns the truth about
# twelve seconds into side one rather than at the end of it.
OUTPUT_CHECK_INTERVAL_S = 10.0

# How often, while an album is playing, to ask OwnTone whether it still is.
#
# Shares the output check's cadence and its reasoning: one cheap GET on the
# same 10s beat rather than a second polling rhythm to reason about. The event
# being watched for - the last groove running out - is not urgent, it just has
# to be noticed before the next card lands, and nobody taps a card within ten
# seconds of side two ending.
PLAYBACK_CHECK_INTERVAL_S = OUTPUT_CHECK_INTERVAL_S

# What OwnTone reports in /api/player once the queue has played out. A card
# lifted mid-track gives "pause"; only a finished (or stopped) queue gives
# this. Confusing the two would throw the place away on every lift.
_FINISHED_STATE = "stop"


class State(enum.Enum):
    IDLE = "idle"
    PLAYING = "playing"
    PAUSED = "paused"


class _Outcome:
    """Whether the guarded OwnTone interaction actually got through."""

    __slots__ = ("ok",)

    def __init__(self) -> None:
        self.ok = True


class Controller:
    def __init__(self, owntone, cards, snapshot, config,
                 clock: Callable[[], float] = time.monotonic,
                 wall_clock: Callable[[], datetime.datetime]
                 = datetime.datetime.now) -> None:
        self._owntone = owntone
        self._cards = cards
        self._snapshot = snapshot
        self._config = config
        self._clock = clock
        # Local wall-clock time, and used for exactly one thing: which side of
        # the nightly reset hour we are on. Kept separate from `clock` rather
        # than replacing it, because every *duration* here must stay on the
        # monotonic clock - an NTP step mid-evening would otherwise either fire
        # a release instantly or park a paused card for hours. Injected so the
        # reset can be tested without sleeping or moving the system clock.
        self._wall_clock = wall_clock

        # Three threads share one Controller: the reader (present/removed),
        # the tick thread (grace expiry) and Flask's workers (status reads).
        # Re-entrant because the public methods call internal helpers and one
        # of those may one day call another public method.
        #
        # The lock guards *mutation* only. The four public attributes are read
        # without it from /api/status: each is a single attribute load, which
        # cannot tear, and the alternative is an admin page that hangs for as
        # long as _release() spends inside OwnTone. A status page that catches
        # the state a moment before now_playing is a cosmetic flicker; a status
        # page that will not load is the operator's only window going dark.
        self._lock = threading.RLock()

        self.state = State.IDLE
        # Management mode: cards identify themselves but do not play. Sitting
        # down to register a stack of cards while each tap starts an album is
        # the wrong experience, especially with the speakers in a living room.
        # Deliberately NOT persisted - a restart returns to a working jukebox,
        # because a box that silently refuses to play is worse than one that
        # forgot a setting.
        self.management_mode = False
        self.last_error: str | None = None
        self.now_playing: str | None = None
        # Every scanned UID, known or not — this is what learn mode reads.
        self.last_seen_uid: str | None = None
        self.last_seen_at: float = 0.0
        # The card on the platter right now: what the reader last announced and
        # we acted on. Cleared whenever we stop believing anything is playing.
        self._last_uid: str | None = None
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

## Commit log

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2026-09-18 Assert decoded JSON payload rather than byte formatting
    The test asserted an exact request body including the spacing that
    json.dumps happens to emit. httpx's json= serialises compactly, so the
    test failed against the idiomatic implementation and the client was
    hand-encoding the body with json.dumps + content= to satisfy it.
    That inverted the dependency: production code was shaped by an
    over-specified test. Separator spacing is not part of the contract.
    Compare the decoded payload instead and restore httpx's json=.
    [owntone.py, test_owntone.py]
2026-09-18 Harden the jukebox against restarts, API errors and bad data
    Four failure modes that each ended with the box silent, restarting, or
    lying about its state. Test-first in every case.
    controller: a re-presented card while PLAYING is now a no-op. If the
    reader double-fires a present event for a card that never left the
    platter, the old code fell through to a full play_album and restarted the
    album from track 1 mid-listen -- the exact behaviour the bump window
    exists to prevent. The UID is still recorded for learn mode first, and a
    different card while PLAYING still switches immediately.
    controller: OwnTone transport/HTTP failures no longer escape. owntone.py
    raises httpx.HTTPStatusError on any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
    [cards.py, controller.py, owntone.py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]
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2026-09-18 Bound the OwnTone client timeout to 3s
    The controller holds its lock across _release(), so a slow OwnTone call
    parks the reader thread and delays card detection. With the previous 10s
    timeout, an unreachable OwnTone could stall card reads for ~40s across the
    four calls a release makes.
    OwnTone runs on localhost. A call taking longer than 3s means it is wedged,
    not busy, so the shorter timeout costs nothing and bounds the stall.
    [owntone.py]
2026-09-18 Stop a corrupt cards.yaml from permanently silencing the box
    A power cut mid-save could leave a zero-length or half-written cards.yaml.
    load() caught only FileNotFoundError, so the resulting yaml.YAMLError escaped
    the controller's guard, propagated out of the reader loop on every tap, and
    made /api/cards 500 -- so the admin page could not even explain why the box
    had gone silent.
    load() now degrades to an empty registry on any read or parse failure, matching
    the posture outputs.py already takes. A file that parses badly is renamed aside
    as cards.yaml.corrupt-<stamp> rather than left in place to be overwritten by the
    next save: the registry is hand-built card by card and painful to recreate,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
    [cards.py, test_cards.py]
2026-09-18 Keep a hand-edited config from crash-looping or half-starting the service
    Config.load() caught only FileNotFoundError and did no type checking, so a file
    edited over SSH could brick the box in four realistic ways: a stray tab raised
    yaml.YAMLError at startup, uncaught, and Restart=always turned that into a
    crash loop every five seconds; a top-level list or scalar did the same via
    AttributeError on .items(); grace_period_s: ninety constructed fine and then
    raised TypeError inside the tick loop every second, so the speakers were never
    released; and a quoted web_port killed the Flask thread at startup, leaving the
    service running with no admin page and nothing to restart it.
    Loading now degrad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
    [config.py, test_config.py]
2026-09-18 Make card registration explain itself instead of failing silently
    Three ways the admin page could leave you with no idea what happened:
    - A malformed POST hit payload["name"] directly, so a missing field was a
    KeyError and a 500 with nothing useful in it. Missing or non-string fields
    now come back as a 400 naming what is wrong.
    - add_card never checked that 'path' existed under library_root, so a typo
    saved happily and surfaced much later as a card that queues nothing when
    tapped -- the 'I tapped my card and nothing happened' experience the box is
    supposed to be free of. The path is now resolved inside the library root and
    rejected with the offending value if it is missing, not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
    [test_controller.py, test_owntone.py, test_web.py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]
2026-09-18 Let the service write its card registry, and survive an OwnTone crash
    Two ways the deployed box was dead on arrival or dead by morning:
    - The unit runs as pi, cards_file points into /etc/nfc-jukebox, and
    provisioning chowned only /var/lib/nfc-jukebox. CardStore.save() writing
    cards.yaml.tmp into a root-owned 0755 directory raised PermissionError,
    unhandled, so every single card registration 500ed and the box could never
    be taught an album. The unit now declares ConfigurationDirectory= and
    StateDirectory=, which is the intent itself -- systemd creates both with the
    right ownership before ExecStart, on every start, so a restored SD card or a
    hand-run install cannot silently miss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
    [owntone.py]
2026-09-18 Keep the box playing, and keep the speaker choice, when OwnTone misbehaves
    Five ways the state machine broke its own promises -- never be silent with no
    explanation, and make the output choice stick.
    - _restore_outputs() and play_album() shared one _guarded block, so a HomePod
    that is powered off but still in OwnTone's list from a cached mDNS record
    made /api/outputs/set fail and skipped playback entirely. Card on the
    platter, nothing playing, state IDLE. The spec is explicit: the device being
    unreachable means play locally anyway and surface it. Output selection is
    now its own failure domain and falls back to the local soundcards; playback
    is attempted regardless.
    - _guarded c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
    [controller.py, test_controller.py]
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2026-09-18 Set bump window from measured hardware, not a guess
    Spike 2 on the real hardware: a stationary NTAG213 on the PN532 over UART
    showed a 35ms worst-case gap between presence reads over ~11s. The original
    3s guess was ~85x too long - a deliberate lift-and-replace would have
    resumed instead of restarting the album.
    0.25s is ~7x the measured gap and below human lift-and-replace speed.
    Measured on a bare board; an enclosure will widen the gap, so the comment
    points at spikes/presence_check.py for re-measuring. It is a config value,
    so retuning needs no code change.
    Also stops two config tests asserting the literal 0.5 when what they
    actually verify is fallback-to-default; they now assert the de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
    [config.py, presence_check.py, test_config.py]
2026-09-18 Fix album ordering against a live OwnTone server
    Spike 1 on real hardware found three things, each previously a guess:
    1. Ordering is not optional. With no `order by`, a 16-track album came back
    as 6 5 12 7 3 8 1 14 ... - "card on plays from track 1" would have been
    broken on every album.
    2. Multi-field ordering is a syntax error: `order by disc asc, track asc`
    returns 500, the comma is rejected. Exactly one sort field is allowed.
    3. `track`/`disc` parse; the JSON-API names `track_number`/`disc_number`
    do not.
    Orders by `path` rather than `track` so a multi-disc album plays correctly
    from a single card - with only one sort field available, `track asc` would
    interleave the discs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
    [owntone.py, test_owntone.py]
2026-09-18 Recover a wedged PN532 by pulsing its reset line
    Restarting the service mid-transaction leaves the PN532 out of frame
    sync: every subsequent ContactlessFrontend() raises ETIMEDOUT and stays
    that way. Observed on the device today - 18 failures in 20 seconds, no
    process holding /dev/ttyAMA0, and a standalone probe failing too, so it
    was the chip and not a stale lock. Pulsing RSTPDN (jumpered to GPIO20 on
    this Waveshare HAT) low for a second fixed it on the next open.
    The old retry loop would have spun at 1/sec forever, leaving a box that
    looks alive - service active, web admin up - while silently never reading
    a card again. With Restart=always that is one crash away at any time.
    So: after tw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
    [config.py, reader.py, test_config.py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]
2026-09-18 Wire reset_gpio config through to the reader
    The setting was read and validated but never passed to Pn532Reader, so the
    reader always used its own default. Behaviour was correct out of the box
    because the defaults matched, but setting reset_gpio in config.yaml - to
    disable the pulse, or to use a different pin - did nothing.
    Verified as the service user on hardware: `pinctrl set` works without sudo,
    and the unit's group list includes gpio, so the reset path has the access
    it needs.
    [__main__.py]
2026-09-18 Notice when the outputs we asked for stop being the outputs in use
    Every synchronous call on the card path can return success and the record
    can still come out of the wrong speaker: an AirPlay 2 HomePod refuses
    pairing several seconds later, deselects itself, and OwnTone quietly falls
    back to the local soundcard. state=play, last_error=None, wrong audio.
    Remember what we intended to be audible when playback starts, then re-check
    it from tick() every 10s. A newly selected non-local output is a person at
    OwnTone's web UI, so adopt it; anything else lost is reported once and then
    dropped, since re-selecting a receiver that just refused pairing only
    loops. The HTTP reads run outside the lock, w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
    [controller.py, test_controller.py]
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2026-09-18 Debounce card presence in the reader
    tag.is_present is not a level signal. It re-selects the tag to answer, and
    measured on hardware a 4-byte Mifare-Classic-style card lying motionless on
    the reader failed that re-select almost immediately: 725 present/absent
    cycles in 25 seconds, median hold 0.008s. An NTAG213 on the same board held
    solid for 11s+ with 35ms of jitter. The behaviour is entirely a property of
    the card technology.
    Downstream that became ~29 present/removed pairs a second and an unbroken
    play/pause storm at OwnTone. Status read "playing"; the user heard silence,
    because audio never had time to start before the next pause. The controller's
    0.25s bump window could not help - it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
    [__main__.py, config.py, reader.py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]
2026-09-18 Say whether a tapped card is already registered
    Learn mode showed a bare UID next to whatever album happened to be selected
    in the dropdown, which reads as if that album is the card's current mapping.
    With identical-looking cards and nothing but a UID to tell them apart, that
    is actively misleading.
    Status now resolves the last scanned card against the registry, so the page
    can say "Not registered yet" or "Registered to: X", and points the dropdown
    at what a known card actually plays. The auto-selection only fires when the
    scanned card changes, so it cannot yank a selection the user is mid-way
    through making.
    Resolved in the web layer rather than the controller: this is a display
    concern a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
    [test_web.py, web.py]
2026-09-18 Fix the admin page blanking its own card table
    Three faults, one visible symptom: the page showed no registrations at all,
    which reads as data loss. The data was never touched.
    1. A template edit added getElementById('known') to the script but never
    added the element - the Python replace that should have inserted it
    looked for &mdash; while the file contains a literal em dash, so it
    matched nothing and failed silently. refresh() then threw on its first
    run, before it reached the card table.
    2. refresh() had no error handling, so any failed poll - a restart
    mid-fetch - took the whole render down with it.
    3. The card table was replaced unconditionally from the fetch result, so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
    [test_web.py, web.py]
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2026-09-18 Show unassigned albums, and make the picker usable at library scale
    /api/albums now reports which albums already have a card, plus totals, so
    the page can answer the question actually being asked while registering:
    what still needs one. With 168 albums and 7 cards that was invisible, and a
    second card on an album already done only showed up when you tapped it.
    Replaces the select with a datalist input. A few hundred options in a
    dropdown is unusable and only gets worse; type-ahead comes free with no
    library. A checkbox filters to albums without a card, and typing an album
    that already has one says so before you save rather than after.
    [test_web.py, web.py]
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2026-09-18 Add management mode and album artwork to the admin page
    Management mode: cards identify themselves but do not play. Registering a
    stack of cards while every tap starts an album is the wrong experience with
    speakers in a living room. Enabling it also stops whatever is playing, since
    the point is a quiet box to register against.
    Deliberately not persisted across restarts. A box that silently refuses to
    play is worse than one that forgot a setting, and the only thing advertising
    the mode is an admin page nobody is looking at. The banner is loud for the
    same reason.
    Artwork: the page shows the album art for whichever card is on the reader,
    which makes identifying an unlabelled card immediate.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
    [__main__.py, controller.py, owntone.py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]
2026-09-18 Sort album tracks by disc then track, client-side
    OwnTone's expression grammar accepts exactly one sort field - `order by disc
    asc, track asc` is a syntax error - so a multi-disc album cannot be ordered
    correctly by asking the server. play_album now fetches the tracks, sorts them
    here on (disc, track, path), and queues them by explicit URI.
    Found via M83's "Hurry Up, We're Dreaming": two discs flattened into one
    folder, so both have a track 1. Sorting by track interleaved them, and
    sorting by path interleaved them identically because the filenames collide
    the same way. The tags were correct all along. Sorting on (disc, track) also
    picks up a track stranded in a sibling folder and puts it in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
    [owntone.py, test_owntone.py]
2026-09-18 Treat disc 0 as disc 1 when ordering an album
    Disc numbering starts at 1, so 0 or missing means "unset" and must sort with
    disc 1 rather than before it.
    Found on Fatboy Slim's "Better Living Through Chemistry": two tracks that
    belonged to the album were filed elsewhere in the library and kept disc=0
    from their old tags. Moving them in gave an album of ten disc-1 tracks and
    two disc-0 ones, and sorting 0 first opened the album with tracks 11 and 12.
    Caught by verifying the repaired albums actually queue in order rather than
    trusting the track count.
    [owntone.py, test_owntone.py]
2026-09-18 Pin the empty-selection fallback with a test
    The behaviour was already correct and well argued in a comment, but nothing
    tested it: removing the guard it depends on breaks it silently. Verified the
    test fails when that guard is removed.
    Worth pinning because it is the one case where "leave the selection alone"
    must NOT apply. Nothing selected is a broken state rather than a choice - it
    guarantees silence - and it happened for real today, with OwnTone coming up
    with no speakers selected at all.
    [test_controller.py]
2026-09-18 Add shut down and restart to the admin page
    Pulling the plug on a running Pi is how SD cards get corrupted, and this is
    an appliance that will get unplugged. A button is the cheapest way to make
    the safe option the easy one.
    Scoped deliberately: the endpoint accepts only "poweroff" or "reboot" and
    nothing else reaches a shell, and the sudoers grant names exactly those two
    commands. Pi OS ships with NOPASSWD: ALL so the grant is redundant today -
    it is there so the feature survives that being tightened.
    Worth stating plainly: the admin page has no authentication, so anyone on the
    LAN can now power the box off. That is a real widening, accepted because
    anyone who can reach the page could als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
    [test_web.py, web.py]
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2026-09-18 Keep the record on the platter until another one is put on
    Lifting a card is how you pause a record player, and pausing should not
    lose your place. Re-placing a card now resumes where it left off however
    long it has been, rather than restarting side one outside a 0.25s window
    that only ever existed to absorb a dropped read.
    The grace expiry no longer stops and clears the queue - that is what
    destroyed the position. It deselects the AirPlay outputs and nothing
    else, so the HomePods still go idle and are free for other senders,
    which was always the requirement; the queue stays paused where it was.
    A different card clears the queue and starts from track 1, an album that
    plays out forgets its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
    [config.py, controller.py, owntone.py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]
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2026-09-18 Ask every art source and rank, rather than taking the first answer
    First-reply-wins printed the wrong sleeve. A search for Liquid Mike's
    self-titled album returned 'Paul Bunyan's Slingshot' at full resolution,
    looking entirely convincing, and nothing downstream could tell.
    Candidates from all sources are now scored on how well the matched title
    fits before resolution is considered, with artist and album weighted
    separately - scoring them as one string let any album by the right artist
    satisfy a self-titled search. Two thresholds, not one: clearing the floor
    means 'probably not a different album', which is too weak a claim to stop
    searching on, so a merely plausible match still consults the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
    [test_cardart.py]
2026-09-18 Let the jukebox start when the music is not mounted
    This service required /srv/music until the NAS stopped resolving over
    mDNS. The mount failed, systemd refused to start this service and
    OwnTone, and the box went completely silent - no playback, and no admin
    page to say why. From outside it was indistinguishable from a dead Pi,
    and cost an evening of chasing power supplies and SD cards for a fault
    that was neither.
    OwnTone keeps the requirement, because it cannot serve files that are
    not there. This service can render a page, report the missing library,
    and recover on its own once the mount appears. /api/status gains
    library_ok and library_error, and the page shows a banner.
    The check cat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
    [test_web.py, web.py]
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2026-09-19 Add a parametric stand for the card and the Pi
    A slanted face holds the card by gravity rather than by a felt strip, and
    the back is left open so the Pi's own ports are reachable - no panel
    cutouts to get wrong and no internal extension cables.
    The Pi is centred rather than shifted to put the antenna behind the
    card's middle: shifting an 85mm board to do that pushes it 8.5mm past the
    edge of a 112mm panel, and buys nothing, because a card-format tag has
    its coil around the whole perimeter and only needs the reader somewhere
    behind it.
    Ships a stepped test coupon, because panel thickness is the one dimension
    that fails as intermittent flapping rather than an honest no-read.
    [stand.scad]
2026-09-19 Make the stand a designed object, not a bracket
    Chamfered arrises, radiused vertical corners, a shadow reveal round the
    base and a cut-back top, so it reads as a cabinet next to a hi-fi rather
    than a printed wedge. The card now drops into a shallow rebate instead of
    leaning on an applied shelf, which leaves the front as one clean line.
    Dropped the thumb scoop: it cut a hole in the middle of the face and read
    as damage. The card leans proud in the rebate and lifts out by its face.
    Three geometry bugs found by actually rendering it:
    Face features were rotated about Y, but the body leans in the YZ plane,
    so every one of them was tilted along the wrong axis and the standoffs
    hung in front of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
    [stand.scad]
2026-09-19 Rake the sides in, and keep the antenna window out of the card rebate
    The taper is the arcade-cabinet move: straight sides read as a box,
    angled ones as a made object. Bounded by an assertion, since the card is
    square and the rake must not close in on its top corners.
    The window and the rebate are cut from opposite faces but both measured
    from the front: the window leaves window_t of material there, the rebate
    removes rebate_d from it, so anywhere they overlapped there was nothing
    left at all and the face opened into a slot - regardless of how thick the
    panel was. The first fix asserted on the sum of the two depths, which was
    the wrong quantity entirely and still let it through.
    The window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
    [stand.scad]
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2026-09-19 Take the HAT's coil position from Waveshare's drawing
    No reason to make anyone measure a documented board. Waveshare publish a
    dimension drawing for the PN532 NFC HAT: it is 85 x 56 mm - the same
    footprint as the Pi, not the short 65 mm HAT assumed here - and the coil
    panel is 37.4 x 37.8 mm, centred 17.0 mm along the long axis and 2.3 mm
    across from the board centre, away from the GPIO header. Measured off
    that drawing by scaling from its own 85.00 and 56.00 dimensions.
    The model now derives the Pi's position from where the tag sits on the
    card, which is the one thing only the owner can know, rather than asking
    for the coil offset. hat_flipped mirrors the HAT end-for-end, which is
    usually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
    [stand.scad]
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2026-09-19 Stop thinning the panel behind the coil by default
    The existing build already reads at a distance, so the ~14mm the HAT sits
    at on 11mm standoffs is not the problem I expected it to be. At that gap
    the panel is a small part of the distance, and thinning it to 1.2mm just
    leaves a weak patch behind the card in exchange for nothing.
    window_t now defaults to face_t, which is no thinning at all. It stays a
    parameter for the close-mounted variant, where the HAT nearly touches the
    panel and the thickness genuinely matters.
    [stand.scad]
2026-09-19 Place the Pi from the measured tag position
    Tag centre measured on the cards: 30mm from the left edge, 65mm from the
    top, on the back. Viewing from the front mirrors left to right but not top
    to bottom, so in the model's frame that is +17.5, -17.5 - the lower right
    quadrant from the front, whatever it looks like from behind.
    Unflipped, that puts the Pi within 0.5mm of centred and needs a 76mm
    panel; flipped it would want 144mm. So hat_flipped is false.
    [stand.scad]
2026-09-19 Make the Pi bosses cones so they can actually be printed
    A cylinder projecting from this face is a 90-degree overhang at its root -
    its first layers have nothing under them, which is the 'floating' it looks
    like in a render, and it would have printed as a mess or needed support
    wedged between four posts where the HAT has to sit flat.
    Each boss is now a full-height 45-degree cone. The face leans back 14
    degrees, so the axis points 14 below horizontal and the cone's underside
    lands 31 degrees from vertical - comfortably inside what prints
    unsupported. A cone is also far stiffer at the root, which is where the
    screw load goes.
    Briefly went the other way and specified M2.5 spacers to shorten t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
    [stand.scad]
2026-09-19 Stop the antenna window eating the standoff cones
    Defaulting window_t to face_t turned the thinning off, but the cutter
    still ran 4mm past the panel's inner surface - deliberately, since ending
    flush leaves coincident faces that render as speckle - and that 4mm was
    carving chunks out of the standoff cones behind it. The bosses came out
    with gaps in them.
    The window is now skipped entirely when there is no thinning to do.
    [stand.scad]
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
